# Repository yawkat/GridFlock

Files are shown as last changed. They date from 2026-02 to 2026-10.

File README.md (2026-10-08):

# GridFlock

A gridfinity-compatible baseplate generator for small printer beds. Cuts the base plate into pieces that fit the printer bed and can be linked together using puzzle-style locking connectors. 

<div align="center">
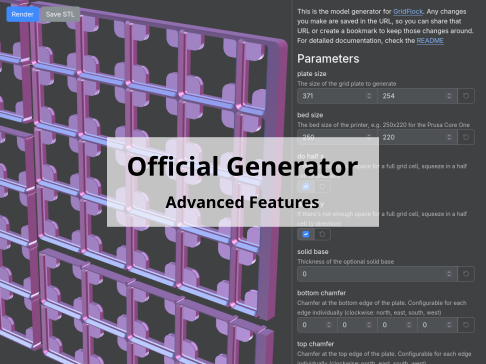
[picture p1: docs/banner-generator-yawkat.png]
Official Generator: Advanced Features
  
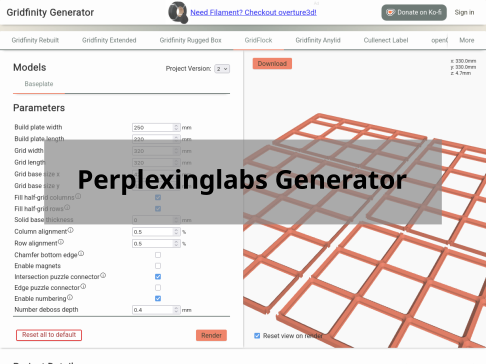
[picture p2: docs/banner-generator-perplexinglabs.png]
Perplexinglabs Generator
  
</div>

An online generator for the latest version version of GridFlock is available [here](https://gridflock.yawk.at/?utm_source=github&utm_campaign=readme_gridflock). You can also use [the perplexinglabs generator](https://gridfinity.perplexinglabs.com/pr/gridflock/0/0) which is a bit more stable. Please also support the model page [on Printables](https://www.printables.com/model/1579487-gridflock-gridfinity-baseplate-generator).

Similar projects include GridPlates (DMCA'd) and GRIPS, but GridFlock is an independent, open-source, clean-room implementation. My goal is truly open community development. If you are missing a feature that is available in GridPlates or GRIPS, please create a GitHub ticket.

GridFlock uses [Gridfinity Rebuilt](https://github.com/kennetek/gridfinity-rebuilt-openscad) (under MIT license) for the baseplate cutter.

For inserting magnets, check out [the jig](#jig).

<!-- openscad -o docs/images/whole.png --camera=0,-10,0,40,0,10,900 -D plate_size='[420, 420]' -->
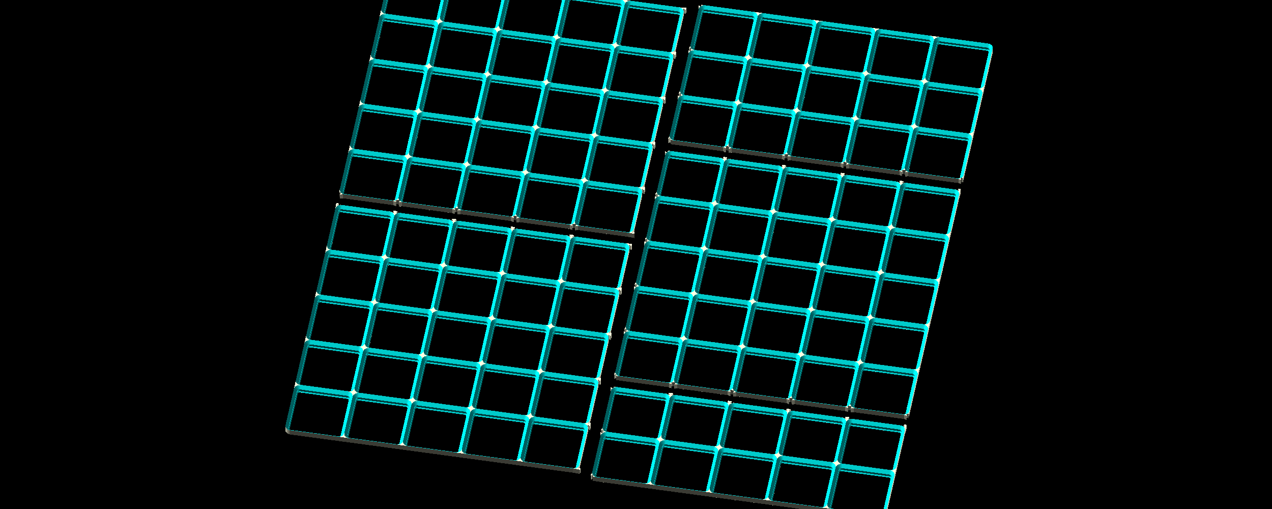
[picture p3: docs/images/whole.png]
Whole plate


<!-- openscad -o docs/images/closeup.png --camera=0,30,0,40,0,25,300 -D plate_size='[420, 420]' -->
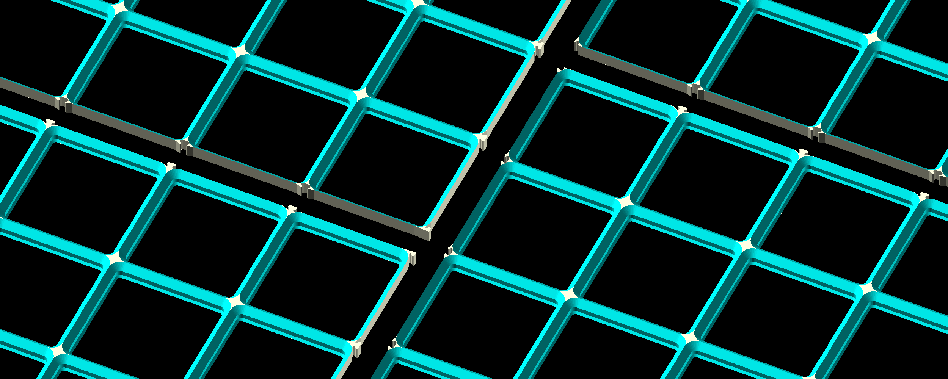
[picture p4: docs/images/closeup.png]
Closeup


- [GridFlock](#gridflock)
  - [Connectors](#connectors)
    - [Intersection Puzzle](#intersection-puzzle)
      - [Connector Fit](#connector-fit)
    - [Edge Puzzle](#edge-puzzle)
      - [Connector Height](#connector-height)
      - [Connector Count](#connector-count)
  - [Magnets](#magnets)
    - [No Magnets](#no-magnets)
    - [Press-Fit magnets](#press-fit-magnets)
      - [Jig](#jig)
    - [Release slot](#release-slot)
    - [Glued magnets](#glued-magnets)
    - [Rounded corner frame](#rounded-corner-frame)
      - [Magnet border](#magnet-border)
    - [Solid frame](#solid-frame)
  - [Click Latch](#click-latch)
    - [ClickGroove](#clickgroove)
      - [Special Bins](#special-bins)
      - [Gap Length](#gap-length)
      - [Tab Length](#tab-length)
      - [Depth](#depth)
      - [Latch Strength](#latch-strength)
      - [Latch Wall Strength](#latch-wall-strength)
    - [Arc Style Latch](#arc-style-latch)
      - [Length](#length)
      - [Distance](#distance)
      - [Latch Strength](#latch-strength-1)
      - [Latch Wall Strength](#latch-wall-strength-1)
      - [Height](#height)
      - [Steepness](#steepness)
  - [Filler](#filler)
    - [None](#none)
    - [Integer Fraction](#integer-fraction)
    - [Dynamic](#dynamic)
  - [Lightweight](#lightweight)
    - [Wall thickness](#wall-thickness)
    - [Connector fill](#connector-fill)
    - [Bottom lip](#bottom-lip)
  - [Corner radius](#corner-radius)
  - [Alignment](#alignment)
  - [Custom cell size](#custom-cell-size)
  - [Solid base](#solid-base)
  - [Bottom Chamfer](#bottom-chamfer)
  - [Top Chamfer](#top-chamfer)
  - [Numbering](#numbering)
    - [Squeezed number](#squeezed-number)
  - [Plate Wall](#plate-wall)
    - [Top plate wall](#top-plate-wall)
    - [Bottom plate wall](#bottom-plate-wall)
    - [Variable wall height](#variable-wall-height)
  - [openGrid Adapter](#opengrid-adapter)
    - [Adapter types](#adapter-types)
      - [Standard openGrid](#standard-opengrid)
      - [openConnect](#openconnect)
  - [Intersection Holes](#intersection-holes)
    - [Screw dimensions](#screw-dimensions)
    - [Intersection magnets](#intersection-magnets)
      - [Magnet dimensions](#magnet-dimensions)
      - [Magnet floor](#magnet-floor)
      - [Magnet release hole](#magnet-release-hole)
    - [Hole locations](#hole-locations)
      - [Plate corners](#plate-corners)
      - [Plate edges](#plate-edges)
      - [Segment corners](#segment-corners)
      - [Segment edges](#segment-edges)
      - [Other intersections](#other-intersections)
      - [Combined](#combined)
  - [Horizontal Screws](#horizontal-screws)
  - [Thumb Screw](#thumb-screw)
  - [Segmentation](#segmentation)
    - [Horizontal](#horizontal)
    - [Vertical](#vertical)
    - [Separate edge padding](#separate-edge-padding)
  - [Edge Adjustment](#edge-adjustment)
    - [Shifting the grid](#shifting-the-grid)
    - [Adding empty space](#adding-empty-space)
    - [Squeezing in extra cells](#squeezing-in-extra-cells)
  - [Top Slice](#top-slice)
  - [Stacked Print](#stacked-print)
    - [Segment Gap](#segment-gap)
    - [Duplicates](#duplicates)
    - [Flipping](#flipping)
    - [Top Slice](#top-slice-1)
  - [Cell override](#cell-override)
    - [Normal cell](#normal-cell)
    - [Solid](#solid)
    - [Empty](#empty)
    - [Irregular Shapes](#irregular-shapes)
  - [Building from source](#building-from-source)
  - [Why the name?](#why-the-name)

## Connectors

When the plate size exceeds your printer's bed size, GridFlock will split the plate into multiple pieces called 'segments'. To connect these segments, multiple connector designs are available.

### Intersection Puzzle

[Interactive example](https://gridflock.yawk.at/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)

This mode adds small puzzle-style connectors at cell intersections. This is similar to GridPlates and GRIPS, and relatively easy to print. However, in my experience, these connectors can sometimes lead to gaps between the segments. The shape of these connectors is fixed in [puzzle.svg](https://github.com/yawkat/GridFlock/blob/main/puzzle.svg) and cannot be customized without editing the SVG.

<!-- openscad -o docs/images/intersection-puzzle.png --camera=0,30,0,40,0,25,300 -D plate_size='[420, 420]' -->
Intersection puzzle

#### Connector Fit

The intersection puzzle connector is intentionally tight to produce a secure fit. It may be necessary to use a mallet or hammer to connect plates.

If the puzzle connector is too tight for your print settings, you can use the `intersection_puzzle_fit` parameter to produce a looser fit. A value of 0 produces the loosest fit, while 1 is the tightest. Try multiple settings and see which works best for you. Tight fit example (`intersection_puzzle_fit=1`):

<!-- openscad -o docs/images/intersection-puzzle-tight.png --camera=0,0,0,40,0,25,70 -D plate_size='[84, 84]' -D bed_size='[50, 1000]' -D magnets=false -->
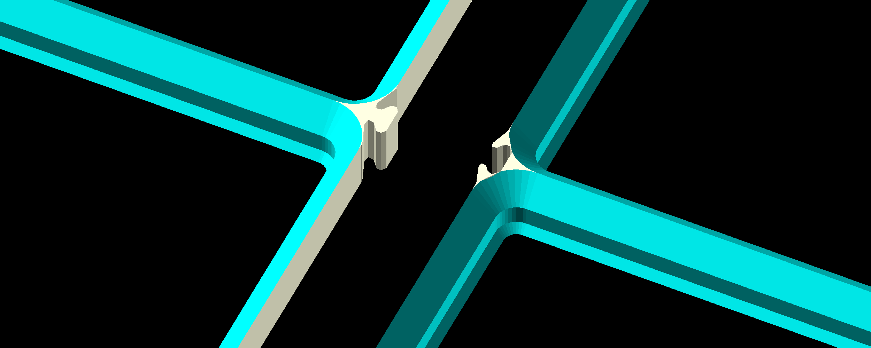
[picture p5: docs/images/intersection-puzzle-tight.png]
Intersection puzzle (tight)


Loose fit example (`intersection_puzzle_fit=0`):

<!-- openscad -o docs/images/intersection-puzzle-loose.png --camera=0,0,0,40,0,25,70 -D plate_size='[84, 84]' -D bed_size='[50, 1000]' -D magnets=false -D intersection_puzzle_fit=0 -->
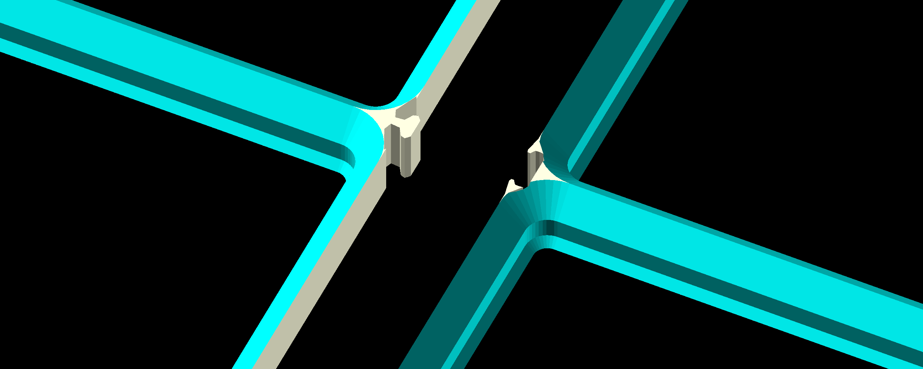
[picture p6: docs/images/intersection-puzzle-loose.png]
Intersection puzzle (loose)


You can find small grids with different fit values to calibrate [on printables](https://www.printables.com/model/1579487-gridflock-gridfinity-baseplate-generator/files).

### Edge Puzzle

[Interactive example](https://gridflock.yawk.at/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)

The edge puzzle mode uses larger connectors placed at the edges of cells, instead of intersections. This leads to a more accurate fit, but is a bit harder to print, and uses more filament.

This connector is a good alternative to the intersection puzzle if the plate has enough vertical height. Try both and see what works best for you. You can also technically enable both at the same time, though I don't know why you would.

* At a segment corner where female connectors are placed on both adjacent sides, the corner could be "cut off" from the rest of the segment. To avoid this, the connector does not use the full height. When *not* using magnets, this can make the connector quite flimsy.
* To avoid interference with the bin in the neighbouring cell, the male connector has a cutout identical to the bin in that cell. Again, if there is not enough vertical height (no magnets), this can make the male connector flimsy.
* To make the female connectors more sturdy and easier to print, an extra "bar" is added at the magnet level, on those edges where a female connector is placed (only if magnets are enabled). You can see it in the screenshot. With this bar, it may be viable to make the connector full-height and avoid the overhang.
* Unlike the intersection mode, the edge puzzle connectors are highly customizable for your circumstances.

<!-- openscad -o docs/images/edge-puzzle.png --camera=0,30,0,40,0,25,300 -D plate_size='[420, 420]' -D connector_intersection_puzzle=false -D connector_edge_puzzle=true -D magnets=true -->
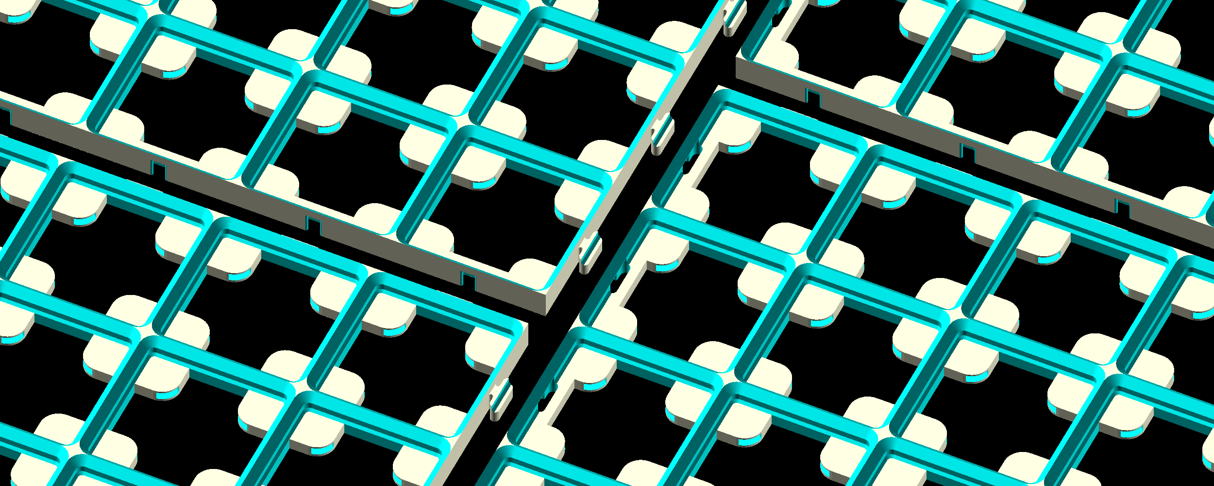
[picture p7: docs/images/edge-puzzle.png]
Edge puzzle


<!-- regression tests: -->
<!-- openscad -o docs/images/edge-puzzle-clickgroove.png --camera=0,0,0,10,0,10,400 -D plate_size='[168, 168]' -D bed_size='[100,100]' -D connector_intersection_puzzle=false -D connector_edge_puzzle=true -D click=true -D click_style=1 -->

#### Connector Height

The edge puzzle connector height can be configured using the `edge_puzzle_height_female` property. The male connector is smaller than this option by `edge_puzzle_height_male_delta`.

With default settings, the male side of the connector can only be pushed into the female side from below. If you increase the `edge_puzzle_height_female` to e.g. 10mm, it will use the full height, and the connector can be pushed from both sides.

<!-- openscad -o docs/images/edge-puzzle-full-height.png --camera=0,0,0,40,0,10,200 -D plate_size='[84, 63]' -D connector_intersection_puzzle=false -D connector_edge_puzzle=true -D 'bed_size=[50, 80]' -D magnets=true -D edge_puzzle_height_female=10 -->
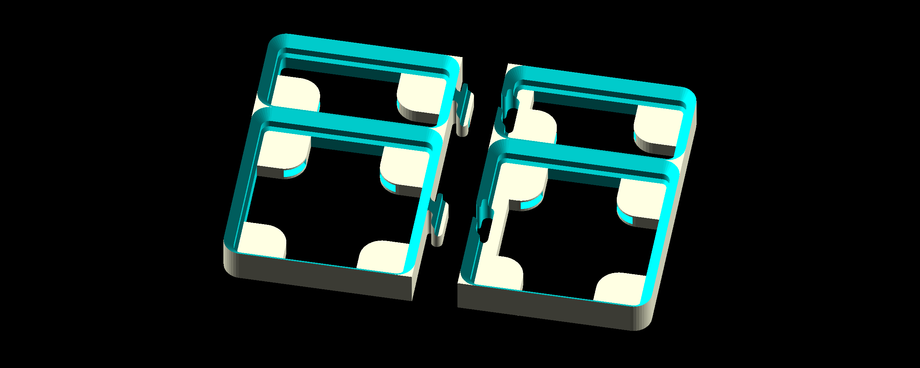
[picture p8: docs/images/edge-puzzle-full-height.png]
Edge puzzle connector with full height


The problem with the full-height connector is that it can lead to unconnected pieces if there is no magnet layer for support. You can see in the below example that the bottom left corner of the top right segment has no connection to the rest of the segment.

<!-- openscad -o docs/images/edge-puzzle-unconnected.png --camera=0,0,0,40,0,10,200 -D plate_size='[84, 84]' -D connector_intersection_puzzle=false -D connector_edge_puzzle=true -D 'bed_size=[50, 50]' -D magnets=false -D edge_puzzle_height_female=10 -->
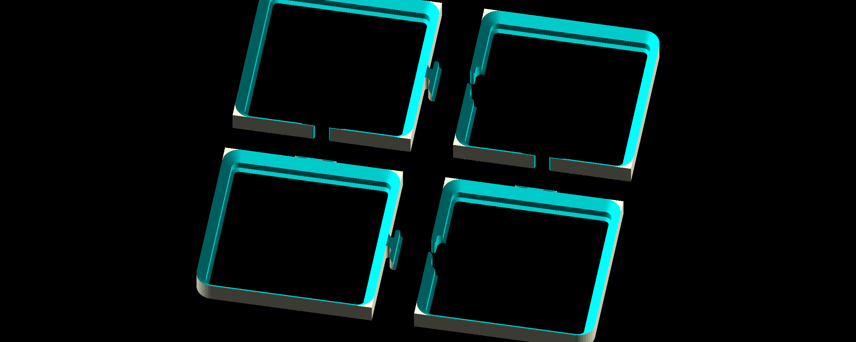
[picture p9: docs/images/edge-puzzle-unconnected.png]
Edge puzzle connector with full height leading to unconnected part


#### Connector Count

The connector count can be configured using the `edge_puzzle_count` property.

<!-- openscad -o docs/images/edge-puzzle-multi.png --camera=0,0,0,40,0,10,200 -D plate_size='[84, 63]' -D connector_intersection_puzzle=false -D connector_edge_puzzle=true -D 'bed_size=[50, 80]' -D magnets=true -D edge_puzzle_count=3 -->
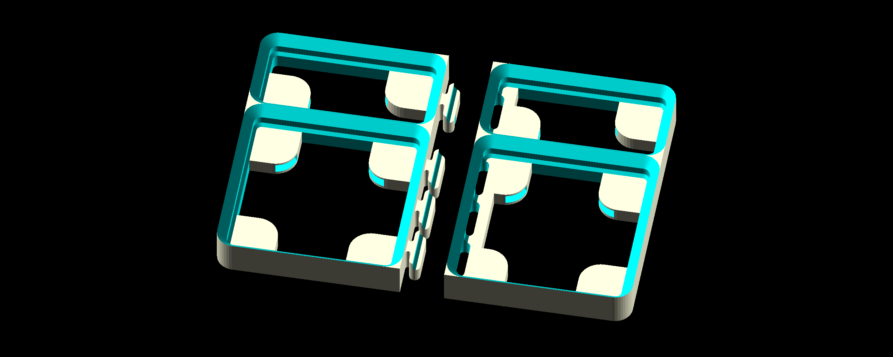
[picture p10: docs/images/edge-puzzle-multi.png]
Multiple edge puzzle connectors


## Magnets

GridFlock supports the standard Gridfinity magnet layout. Note that magnets require additional vertical room.

Magnets are assumed to be round. The exact size can be configured with the `magnet_diameter` and `magnet_height` options.

### No Magnets

It is possible to disable magnets altogether to save filament and vertical space.

<!-- openscad -o docs/images/magnets-none.png --camera=0,0,0,40,0,10,200 -D plate_size='[105, 63]' -D magnets=false -->
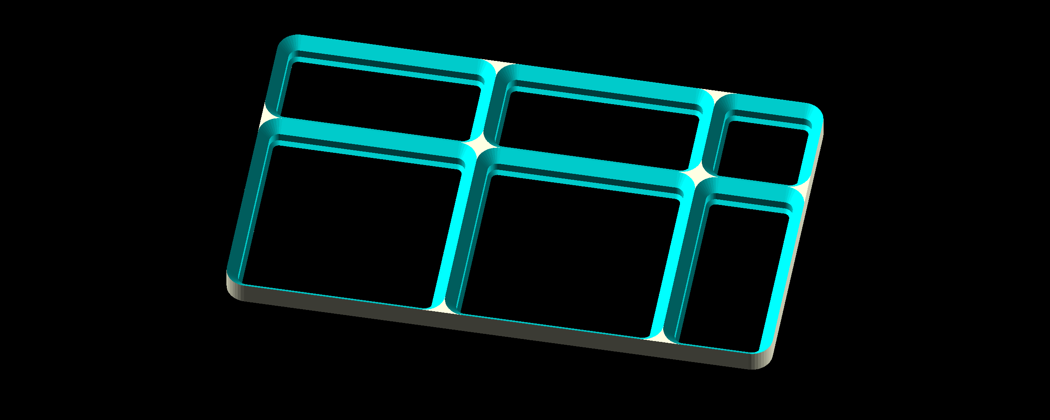
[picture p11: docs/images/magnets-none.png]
No Magnets


### Press-Fit magnets

Press-fit magnets require no glue. The magnets are simply pressed into the pockets from the side. A jig for easily inserting magnets is available [on printables](https://www.printables.com/model/1579487-gridflock-gridfinity-baseplate-generator/files) (thanks @nelsonjchen!).

<!-- openscad -o docs/images/magnets-press-fit.png --camera=0,0,0,40,0,10,200 -D plate_size='[105, 63]' -D magnets=true -->
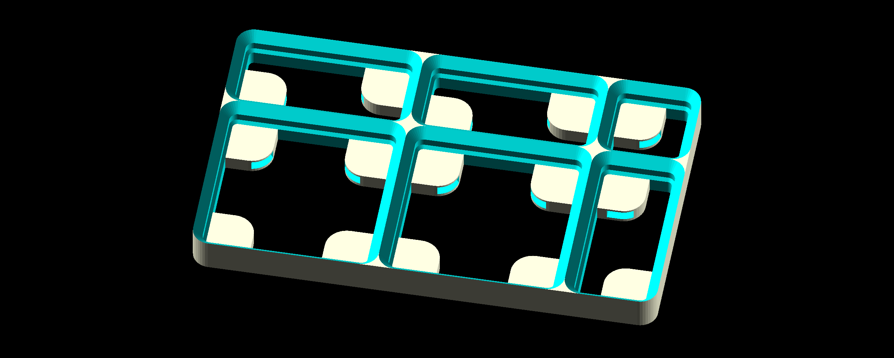
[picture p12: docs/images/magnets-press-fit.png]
Press-fit magnets


The layers above and below the magnet can be configured using the `magnet_top` and `magnet_bottom` options. 

Because the distance to the bin magnets is larger, press-fit magnets make for a weaker connection than glue-in magnets.

#### Jig

GridFlock includes a magnet insertion jig that makes pressing in magnets easy and fast (thanks @nelsonjchen!). You can download the jig [on printables](https://www.printables.com/model/1579487-gridflock-gridfinity-baseplate-generator/files). There is also [a remix available](https://www.printables.com/model/1640587-gridflock-magnet-jig-tweaked) that improves the jig further. Note that the remix is not generated as part of GridFlock, so future geometry changes may not be included (see [issue](https://github.com/yawkat/GridFlock/issues/39)).

The jig prints in two pieces, a main frame and a pusher. The pusher needs to be printed with supports, and should have a high infill percentage.

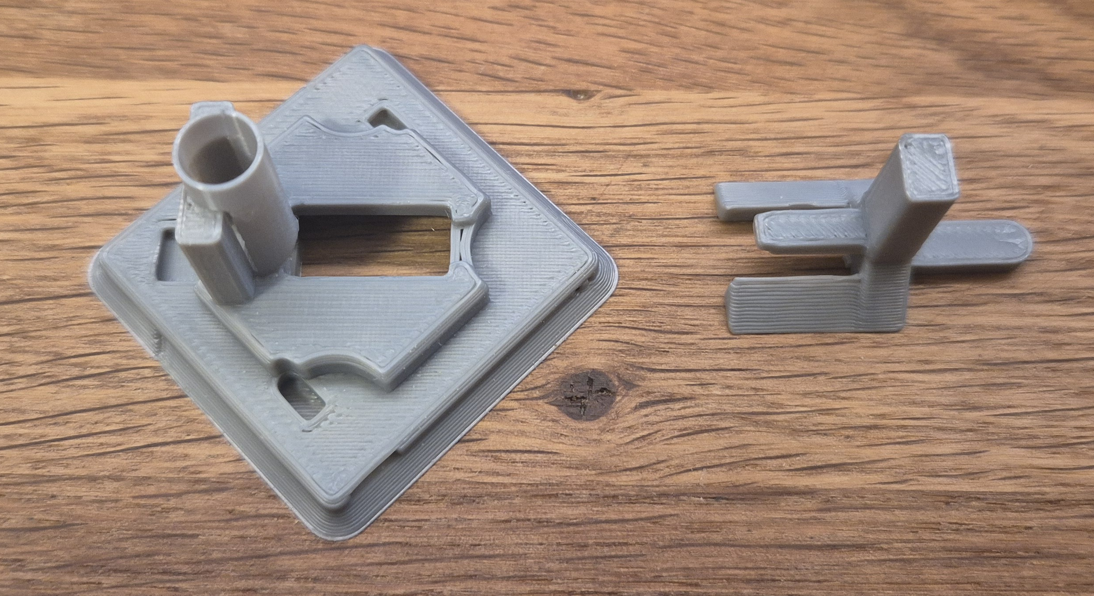
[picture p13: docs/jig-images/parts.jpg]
Jig parts


First, insert the reference magnet. The reference magnet will make sure that any magnets you put into the plate will have the right orientation, and it helps with pulling the magnets into place. Make sure it has the right orientation – see the below instructions on how the jig is used to figure it out. Place the reference magnet in the circled slot:

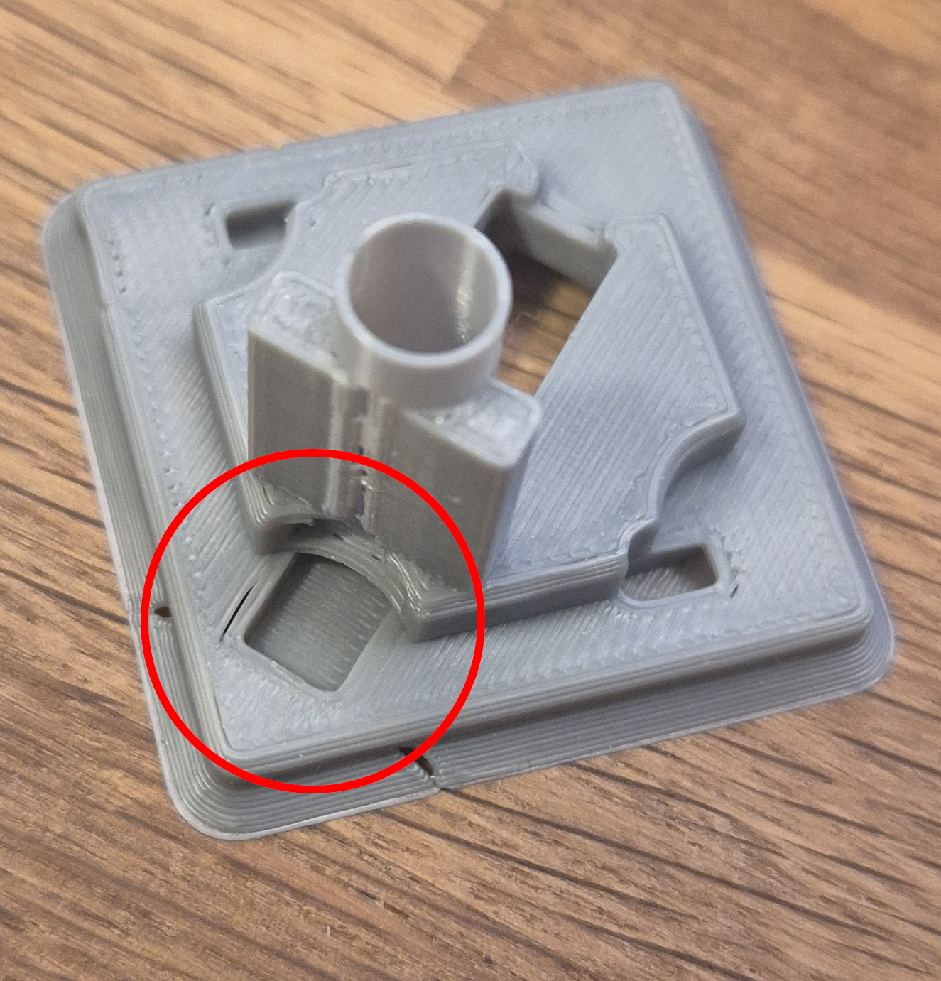
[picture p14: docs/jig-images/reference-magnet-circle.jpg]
The jig with a circle around the reference magnet slot


Next, push the reference magnet into the jig until it is fully seated. Here you can see it halfway:

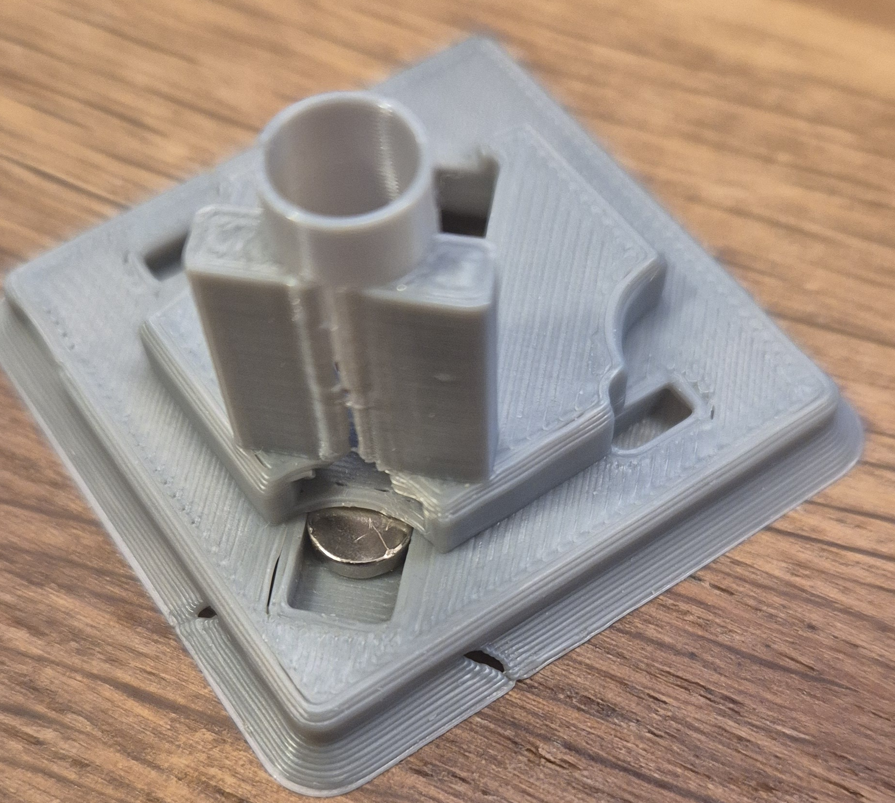
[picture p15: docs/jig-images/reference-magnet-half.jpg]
Reference magnet inserted half-way


Now, place the jig on top of the pusher to finish assembly:

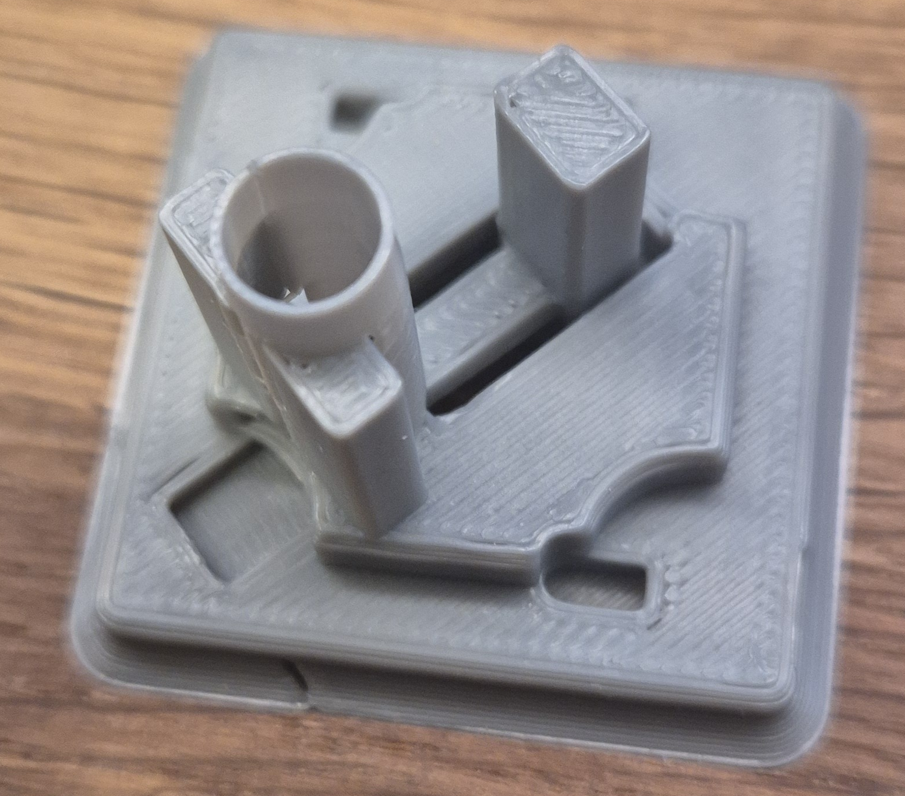
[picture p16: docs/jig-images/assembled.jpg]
Assembled jig


Now that the jig is assembled, you can start using it to populate your baseplate. Load a stack of magnets into the jig, and then place the baseplate upside down on the jig:

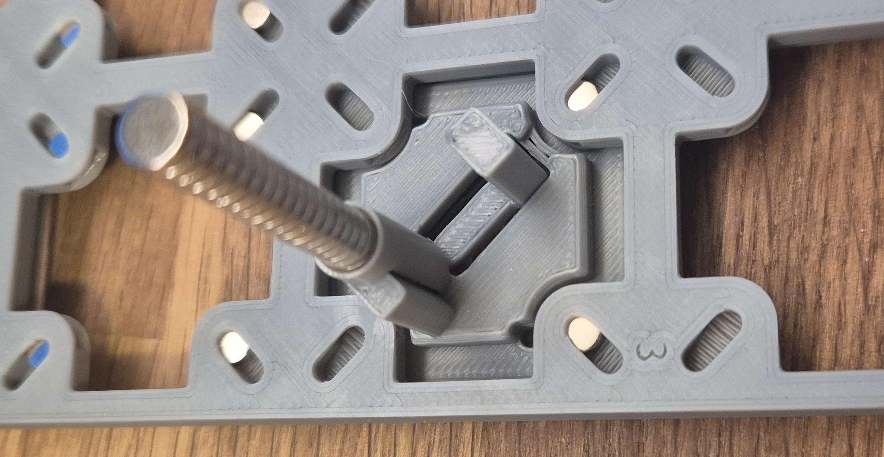
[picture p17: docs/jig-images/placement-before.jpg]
Baseplate on top of the jig


Now you can use the pusher to insert the magnet into the baseplate:

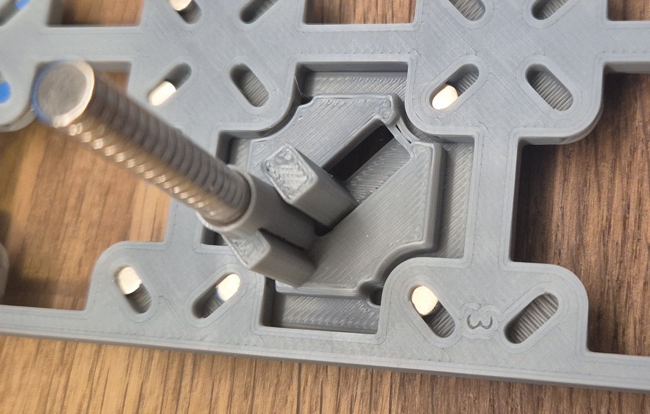
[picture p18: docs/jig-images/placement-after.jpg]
Baseplate on top of the jig with magnet pushed in


Pull the pusher back into its original position to release the baseplate. You can now turn the jig by 90° to insert the next magnet, and then move the baseplate to fill the next square with magnets.

<!-- These images are generated for regression detection purposes. -->
<!-- openscad -o docs/images/jig-main.png --camera=0,0,0,40,0,10,200 -D part='"jig"' mag_insert_jig.scad -->
<!-- openscad -o docs/images/jig-pusher.png --camera=0,0,0,40,0,10,200 -D part='"pusher"' mag_insert_jig.scad -->
<!-- openscad -o docs/images/jig-main-below.png --camera=0,0,0,140,0,10,200 -D part='"jig"' mag_insert_jig.scad -->
<!-- openscad -o docs/images/jig-pusher-below.png --camera=0,0,0,140,0,10,200 -D part='"pusher"' mag_insert_jig.scad -->

### Release slot

On the bottom side of the plate there is a slot so you can push out any inserted magnet with a screwdriver.

<!-- openscad -o docs/images/magnets-press-fit-below.png --camera=0,0,0,140,0,10,200 -D plate_size='[105, 63]' -D magnets=true -->
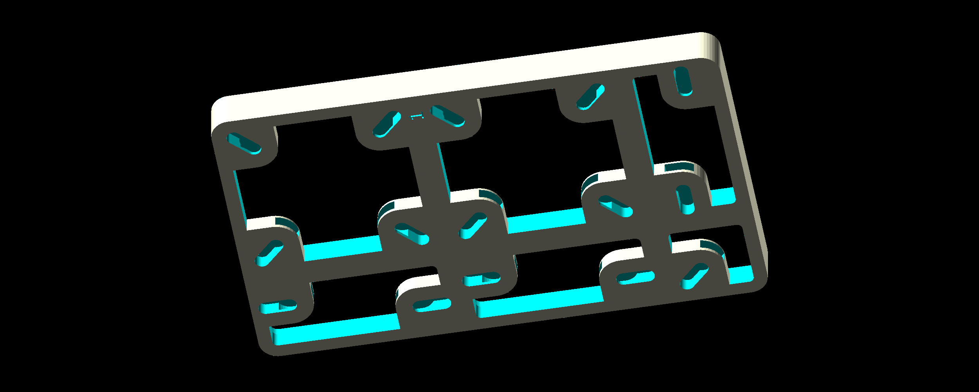
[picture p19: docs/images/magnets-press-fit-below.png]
Press-fit magnets from below


The width of this slot can be adjusted with the `magnet_release_width` setting. Setting this to 0 disables the release slot.

For glue-in magnets, there is a hole instead of a slot. The diameter of the hole is also controlled by `magnet_release_width`.

### Glued magnets

Magnets can also be glued in from the top:

<!-- openscad -o docs/images/magnets-glue-in.png --camera=0,0,0,40,0,10,200 -D plate_size='[105, 63]' -D magnets=true -D magnet_style=0 -->
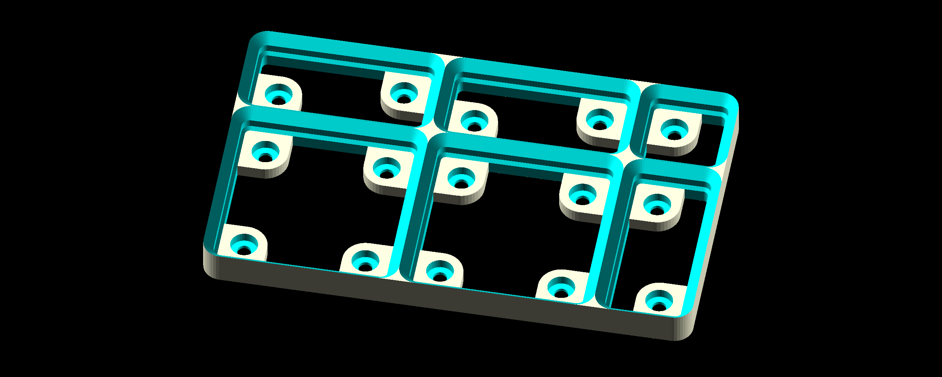
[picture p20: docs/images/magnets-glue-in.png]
Glued magnets (top)


The `magnet_bottom` option is identical to the press-fit version, but the `magnet_top` option is ignored.

Or they can be glued from the bottom:

<!-- openscad -o docs/images/magnets-glue-in-bottom.png --camera=0,0,0,140,0,10,200 -D plate_size='[105, 63]' -D magnets=true -D magnet_style=2 -->
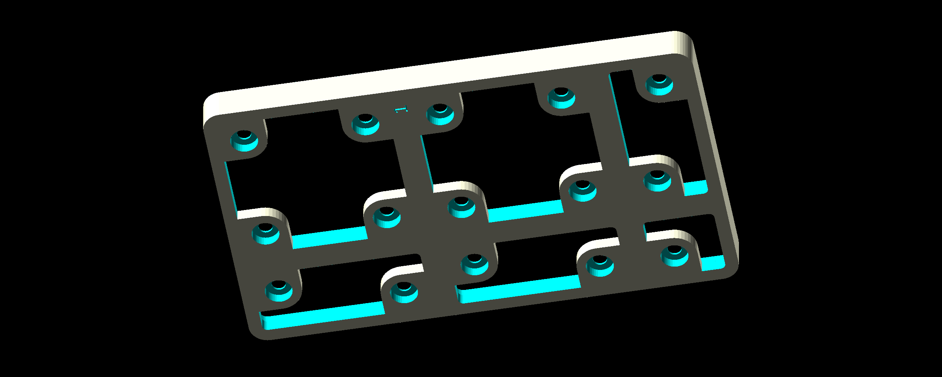
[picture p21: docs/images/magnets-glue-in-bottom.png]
Glued magnets (bottom)


By tuning the magnet size, this last magnet style can also be used to press-fit magnets from the bottom, similar to Gridfinity Refined.

### Rounded corner frame

By default, the vertical space for the magnet is not fully filled in to save filament. This is called the "rounded corner" frame style.

Press-fit magnets

#### Magnet border

To save filament, you can set a lower `magnet_border`:

<!-- openscad -o docs/images/magnet-border-1.png --camera=0,0,0,40,0,10,200 -D plate_size='[105, 63]' -D magnets=true -D magnet_border=1 -D magnet_style=1 -->
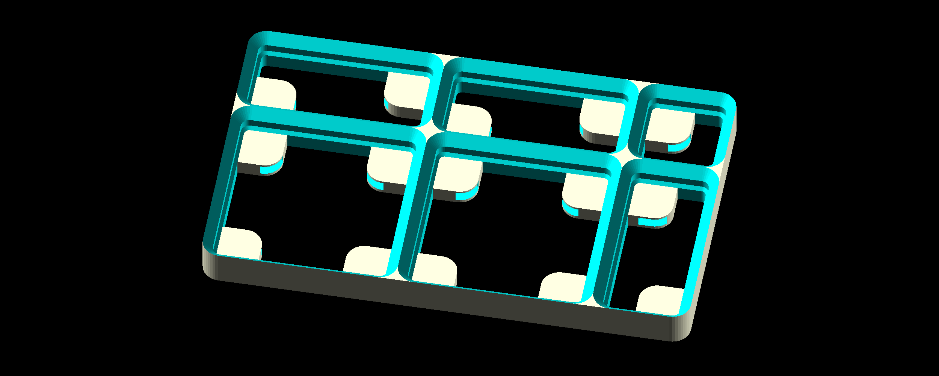
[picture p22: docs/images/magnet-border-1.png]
Magnet border


### Solid frame

Using the `magnet_frame_style` option, you can change the magnet layer to be fully filled in.

> [!WARNING]
> The solid frame style cannot be combined with the press-fit magnet style because there is no way to push the magnets in.

<!-- openscad -o docs/images/magnets-solid.png --camera=0,0,0,40,0,10,200 -D plate_size='[105, 63]' -D magnets=true -D magnet_style=0 -D magnet_frame_style=0 -->
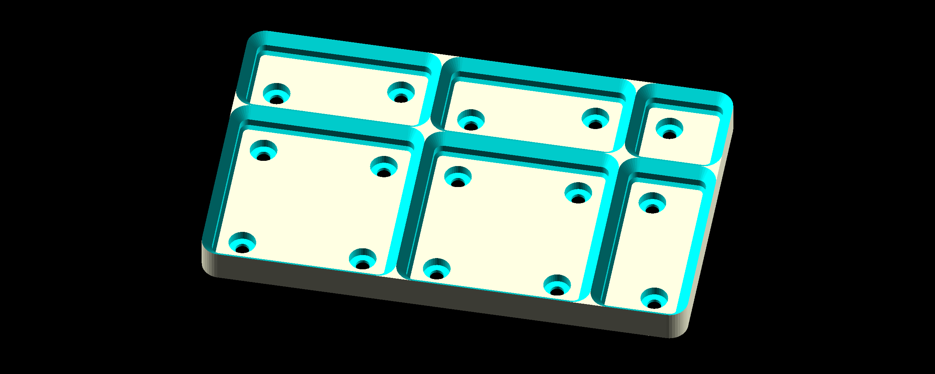
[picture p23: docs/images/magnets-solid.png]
Solid magnet frame


## Click Latch

If you do not wish to use magnets, but still want a more secure fit for your bins, a click latch is an option. A click latch grips the bottom of the bin.

> [!WARNING]
> When a bin is placed on the baseplate, the click latch is under constant mechanical stress. This causes the plastic to deform over time ("creep"), reducing the grip strength. _PLA is very susceptible to this._ PETG is more resistant, but long-term tests are still scarce, so _consider this feature experimental_.

### ClickGroove

Like other click latch designs, a ClickGroove baseplate works with standard Gridfinity bins, with similar creep problems. When used with a ClickGroove bin, however, a special notch in the bin's base allows the baseplate to grab on _without stress_, which reduces long term creep.

<!-- openscad -o docs/images/click2.png --camera=0,0,0,40,0,10,200 -D plate_size='[105, 63]' -D click=true -D click_style=1 -->
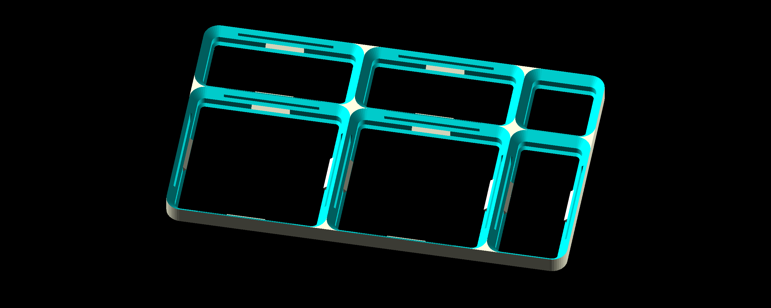
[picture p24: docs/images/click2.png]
ClickGroove baseplate


<!-- regression testing: -->
<!-- openscad -o docs/images/click2-bottom-chamfer-1.png --camera=0,0,0,140,0,10,200 -D plate_size='[86, 86]' -D click=true -D click_style=1 -D bottom_chamfer='[0,0,0,0]' -->
<!-- openscad -o docs/images/click2-bottom-chamfer-2.png --camera=0,0,0,140,0,10,200 -D plate_size='[86, 86]' -D click=true -D click_style=1 -D bottom_chamfer='[1,1,0,0]' -->
<!-- openscad -o docs/images/click2-bottom-chamfer-3.png --camera=0,0,0,140,0,10,200 -D plate_size='[86, 86]' -D click=true -D click_style=1 -D bottom_chamfer='[2,2,1,1]' -->
<!-- openscad -o docs/images/click2-bottom-chamfer-4.png --camera=0,0,0,140,0,10,200 -D plate_size='[86, 86]' -D click=true -D click_style=1 -D bottom_chamfer='[3,3,2,2]' -->

#### Special Bins

To avoid creep and take full advantage of the ClickGroove system, your bins need a compatible groove. There is a template bin with this groove [on printables](https://www.printables.com/model/1579487-gridflock-gridfinity-baseplate-generator/files). To add it to a bin, use the [Gridfinity Rebase tool](https://gridfinity.tools/rebase/). The tool can modify community-created bins, or those created with a generator like [Gridfinity Extended](https://docs.ostat.com/docs/openscad/gridfinity-extended).

<!-- openscad -o docs/images/click2-bin.png --camera=0,0,3,80,0,20,50 clickgroove-base.scad -->
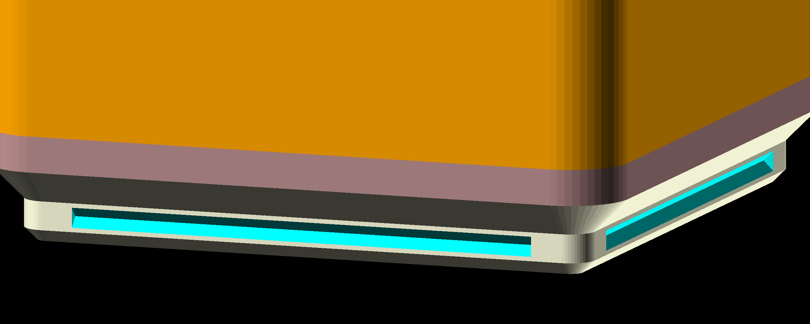
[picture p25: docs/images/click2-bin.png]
ClickGroove bin template


#### Gap Length

The length of the gap behind the click latch can be configured with `clickgroove_gap_length`. A higher value will lead to less resistance when locking and unlocking.

<!-- openscad -o docs/images/click2-gap-length.png --camera=0,0,0,40,0,10,100 -D plate_size='[42, 42]' -D click=true -D click_style=1 -D clickgroove_gap_length=10 -->
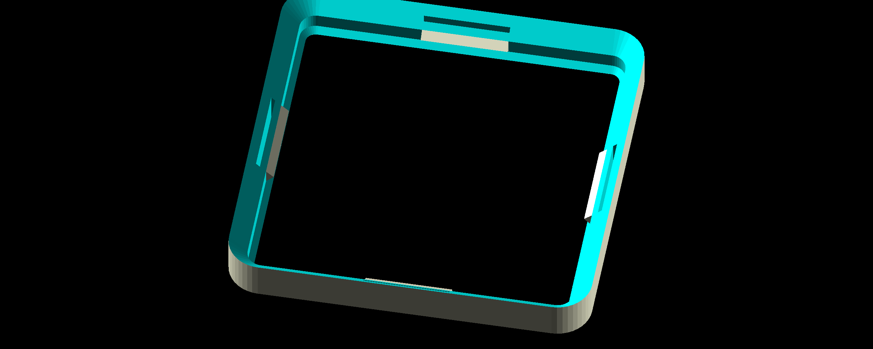
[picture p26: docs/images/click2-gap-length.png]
Click latch with clickgroove_gap_length=10


#### Tab Length

The length of the tab that engages with the bin groove can be configured with `clickgroove_tab_length`.

<!-- openscad -o docs/images/click2-tab-length.png --camera=0,0,0,40,0,10,100 -D plate_size='[42, 42]' -D click=true -D click_style=1 -D clickgroove_tab_length=5 -->
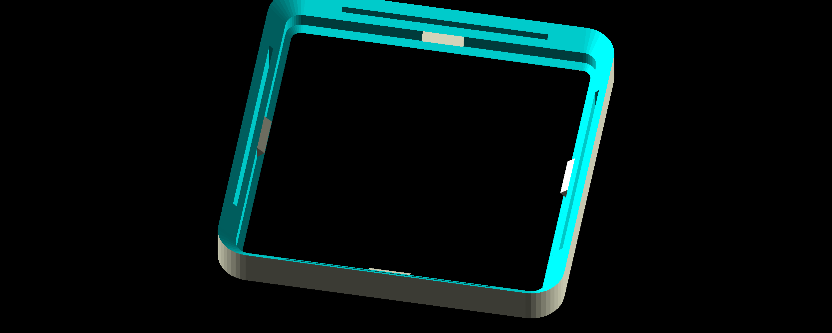
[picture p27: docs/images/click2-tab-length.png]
Click latch with clickgroove_tab_length=5


#### Depth

The depth of the tab can be configured with `clickgroove_depth`. Changing this value has a big impact on latching strength, so be careful.

<!-- openscad -o docs/images/click2-depth.png --camera=0,0,0,40,0,10,100 -D plate_size='[42, 42]' -D click=true -D click_style=1 -D clickgroove_depth=2 -->
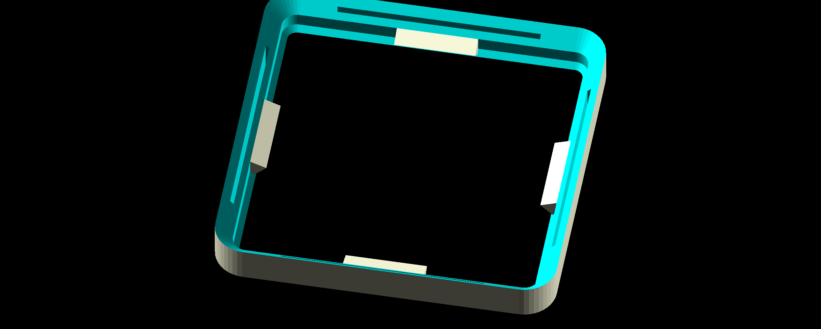
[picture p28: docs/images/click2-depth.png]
Click latch with clickgroove_depth=2


#### Latch Strength

The `clickgroove_strength` property controls the thickness of the latch itself. This is measured from the very bottom of the latch which, if you look at the gridfinity specification, has a chamfer of 0.7mm, so the strength needs to be higher than this to get any reasonable latch height. Here's an example with `clickgroove_strength=2.5` (and `clickgroove_wall_strength=0`, or else there would not be enough space):

<!-- openscad -o docs/images/click1-strength-2.5.png --camera=0,0,0,40,0,10,100 -D plate_size='[42, 42]' -D click=true -D click_style=1 -D clickgroove_strength=2.5 -D clickgroove_wall_strength=0 -->
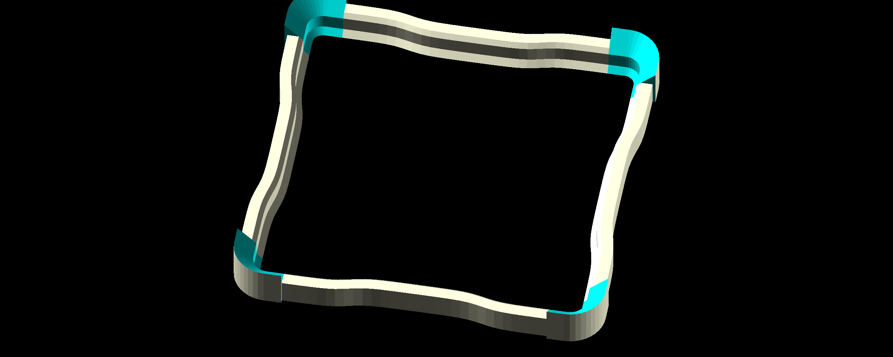
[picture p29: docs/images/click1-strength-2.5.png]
Click latch with clickgroove_strength=2.5


#### Latch Wall Strength

The `clickgroove_wall_strength` property controls the thickness of the wall behind the latch. This wall serves two purposes: It adds rigidity to the baseplate, and it prevents the click latch from bending too far. Note that the wall is measured per cell, so if you have two neighbouring cells, the actual wall thickness will be double this value. An example with `clickgroove_wall_strength=2` (and reduced `clickgroove_strength`):

<!-- openscad -o docs/images/click1-wall-strength-2.png --camera=0,0,0,40,0,10,100 -D plate_size='[84, 42]' -D click=true -D click_style=1 -D clickgroove_strength=0.8 -D clickgroove_wall_strength=2 -->
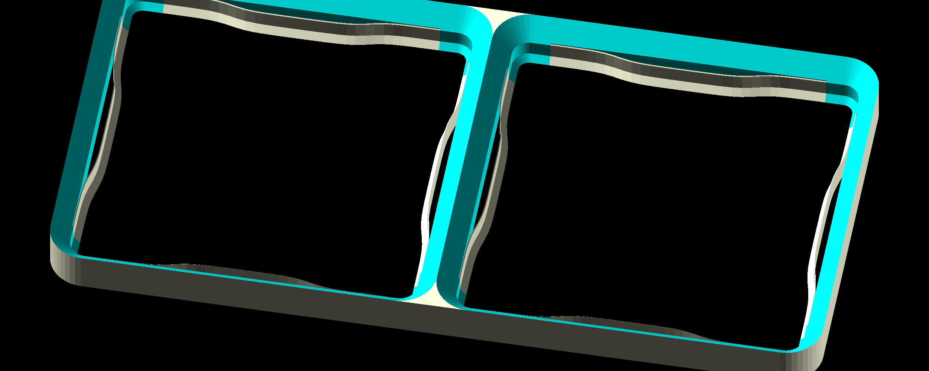
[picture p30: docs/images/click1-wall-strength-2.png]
Click latch with clickgroove_wall_strength=2


### Arc Style Latch

The arc-style latch is a more traditional and robust design. However it is very susceptible to creep.

<!-- openscad -o docs/images/click1.png --camera=0,0,0,40,0,10,200 -D plate_size='[105, 63]' -D click=true -D click_style=0 -->
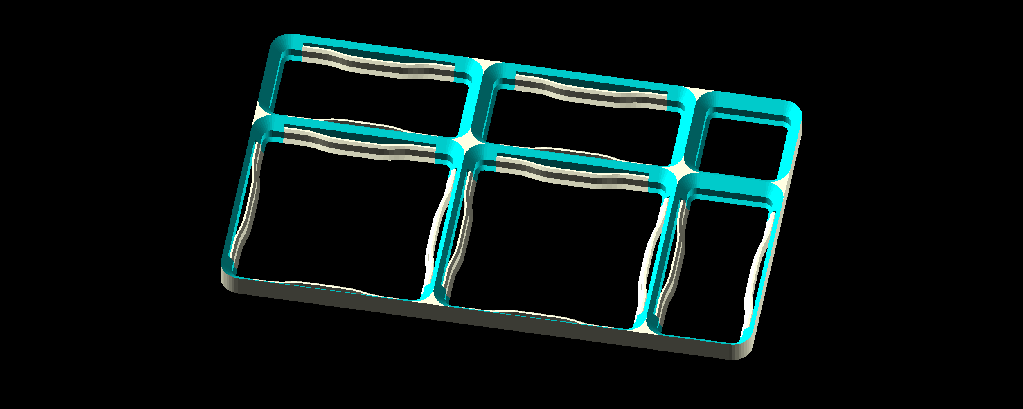
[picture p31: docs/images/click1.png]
Click latch


There are various parameters you can use to tune the click latch mechanism.

#### Length

The latch is composed of two arcs at each end, and an optional middle straight section. The total length of the latch is configured using the `click1_outer_length` property:

<!-- openscad -o docs/images/click1-outer-length-20.png --camera=0,0,0,40,0,10,100 -D plate_size='[42, 42]' -D click=true -D click_style=0 -D click1_outer_length=20 -->
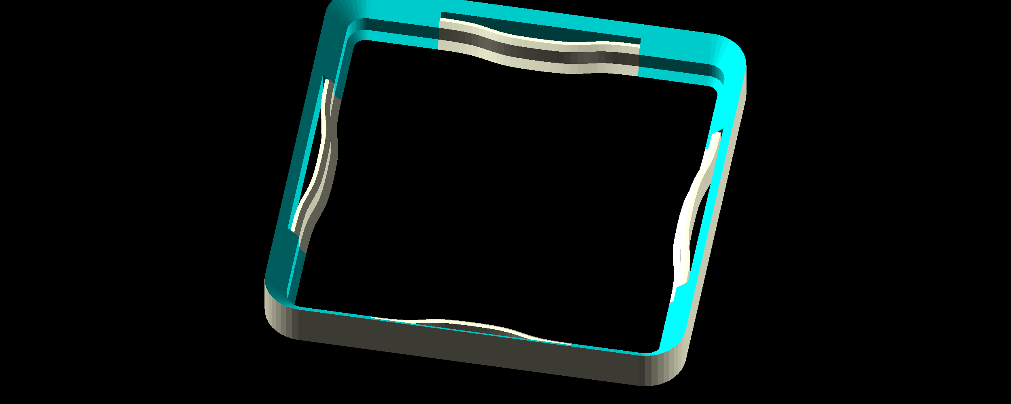
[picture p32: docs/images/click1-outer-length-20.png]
Click latch with click1_outer_length=20


The length of the straight section is configured using `click1_inner_length`, which is 0 by default (no straight section). Here is an example with a 20mm straight section:

<!-- openscad -o docs/images/click1-inner-length-20.png --camera=0,0,0,40,0,10,100 -D plate_size='[42, 42]' -D click=true -D click_style=0 -D click1_inner_length=20 -->
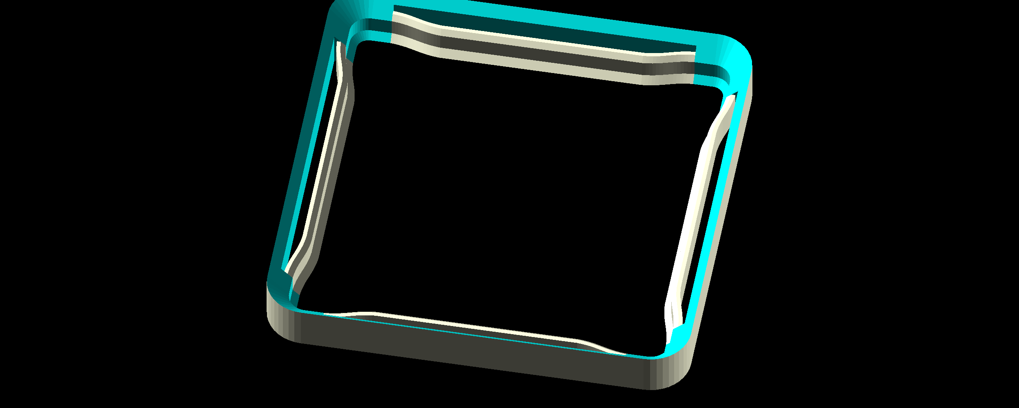
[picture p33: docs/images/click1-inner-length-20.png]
Click latch with click1_inner_length=20


#### Distance

The `click1_distance` property changes the distance that the latch protudes into the bin area. A larger distance can increase grip strength, but makes the bin more difficult to place into the baseplate. Zero distance:

<!-- openscad -o docs/images/click1-distance-0.png --camera=0,0,0,40,0,10,100 -D plate_size='[42, 42]' -D click=true -D click_style=0 -D click1_distance=0 -->
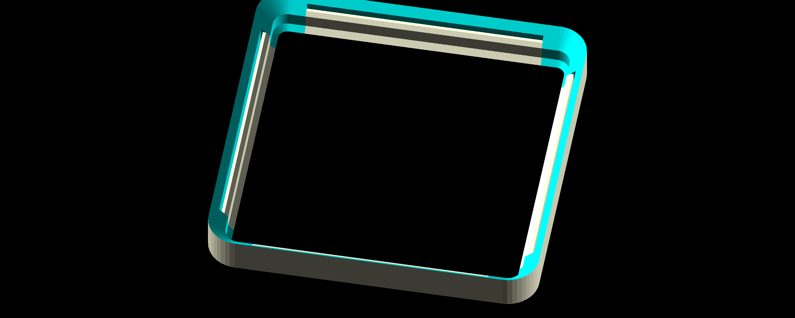
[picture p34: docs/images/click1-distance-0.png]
Click latch with click1_distance=0


5mm distance (don't do this):

<!-- openscad -o docs/images/click1-distance-5.png --camera=0,0,0,40,0,10,100 -D plate_size='[42, 42]' -D click=true -D click_style=0 -D click1_distance=5 -->
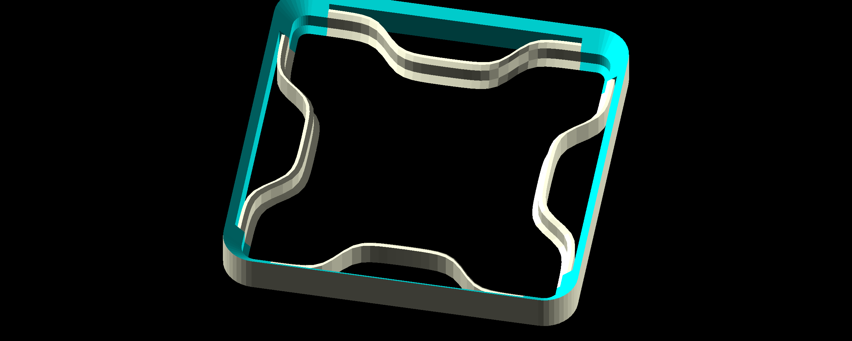
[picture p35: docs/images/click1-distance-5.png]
Click latch with click1_distance=5


#### Latch Strength

The `click1_strength` property controls the thickness of the latch itself. This is measured from the very bottom of the latch which, if you look at the gridfinity specification, has a chamfer of 0.7mm, so the strength needs to be higher than this to get any reasonable latch height. Here's an example with `click1_strength=2.5` (and `click1_wall_strength=0`, or else there would not be enough space):

<!-- openscad -o docs/images/click1-strength-2.5.png --camera=0,0,0,40,0,10,100 -D plate_size='[42, 42]' -D click=true -D click_style=0 -D click1_strength=2.5 -D click1_wall_strength=0 -->
Click latch with click1_strength=2.5

#### Latch Wall Strength

The `click1_wall_strength` property controls the thickness of the wall behind the latch. This wall serves two purposes: It adds rigidity to the baseplate, and it prevents the click latch from bending too far. Note that the wall is measured per cell, so if you have two neighbouring cells, the actual wall thickness will be double this value. An example with `click1_wall_strength=2` (and reduced `click1_strength`):

<!-- openscad -o docs/images/click1-wall-strength-2.png --camera=0,0,0,40,0,10,100 -D plate_size='[84, 42]' -D click=true -D click_style=0 -D click1_strength=0.8 -D click1_wall_strength=2 -->
Click latch with click1_wall_strength=2

Setting the wall strength to 0 disables the backing wall entirely:

<!-- openscad -o docs/images/click1-wall-strength-0.png --camera=0,0,0,40,0,10,100 -D plate_size='[84, 42]' -D click=true -D click_style=0 -D click1_wall_strength=0 -->
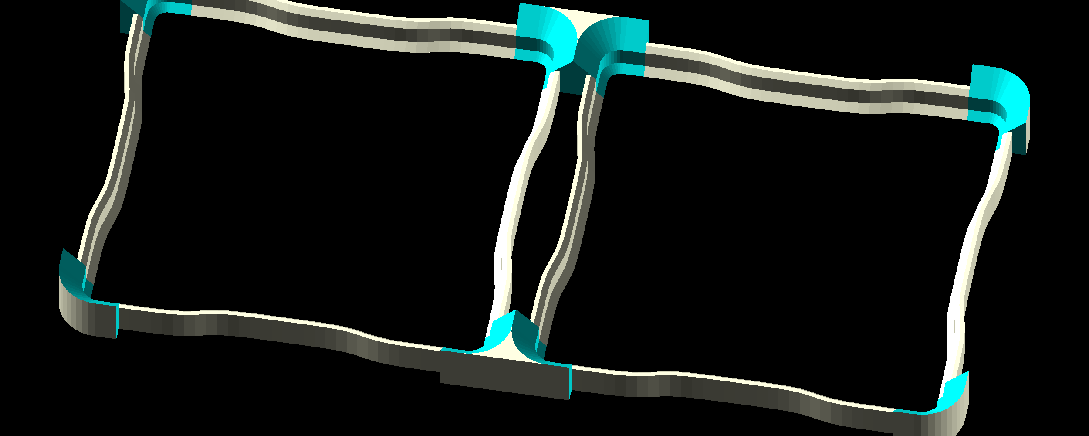
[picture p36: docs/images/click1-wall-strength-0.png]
Click latch with click1_wall_strength=0


#### Height

The `click1_height` property controls the height of the latch.

<!-- openscad -o docs/images/click1-height-0.5.png --camera=0,0,0,40,0,10,100 -D plate_size='[42, 42]' -D click=true -D click_style=0 -D click1_height=0.5 -->
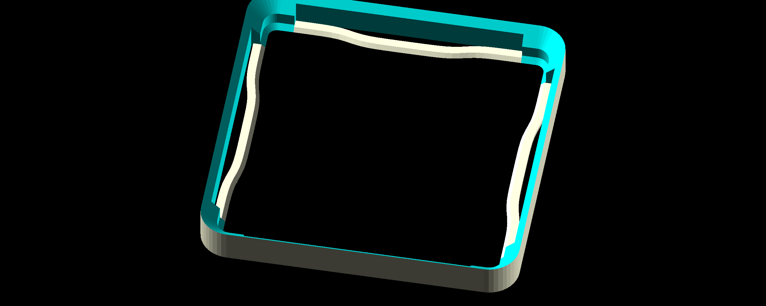
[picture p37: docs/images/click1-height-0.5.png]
Click latch with click1_height=0


#### Steepness

The arcs of the click latch follow a logistic curve, and `click1_steepness` changes the steepness of that curve. Steepness 0.1:

<!-- openscad -o docs/images/click1-steepness-0.1.png --camera=0,0,0,40,0,10,100 -D plate_size='[42, 42]' -D click=true -D click_style=0 -D click1_steepness=0.1 -->
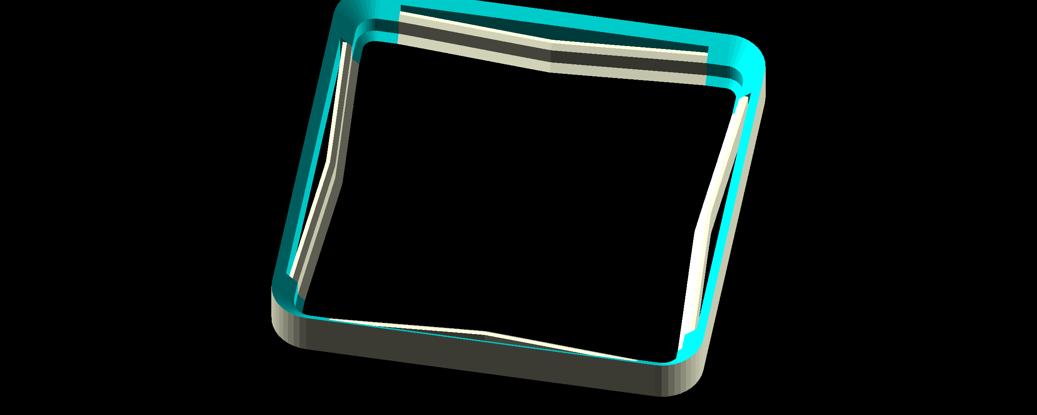
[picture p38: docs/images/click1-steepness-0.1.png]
Click latch with click1_steepness=0.1


Steepness 5:

<!-- openscad -o docs/images/click1-steepness-5.png --camera=0,0,0,40,0,10,100 -D plate_size='[42, 42]' -D click=true -D click_style=0 -D click1_steepness=5 -->
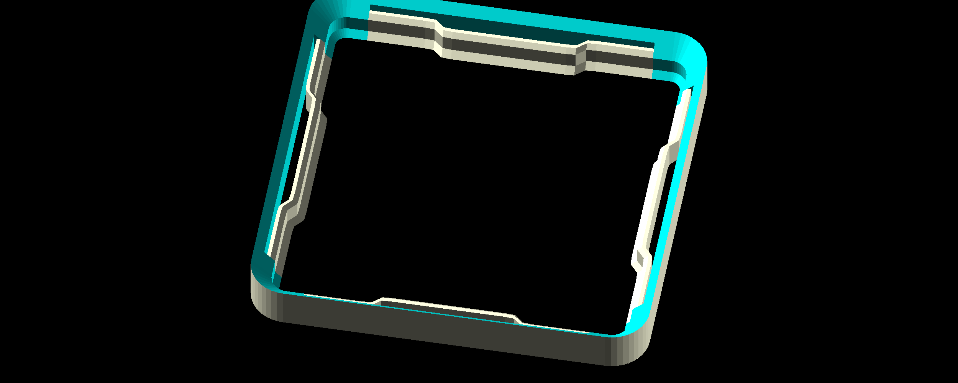
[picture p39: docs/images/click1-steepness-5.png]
Click latch with click1_steepness=5


## Filler

If the baseplate is not a multiple of 42mm, there's some room that can't be used for a full-sized cell. There are different options for what to do with this space.

The filler algorithm can be configured with the `filler_x` and `filler_y` properties.

### None

In `None` mode, the remaining space is simply filled with padding.

<!-- openscad -o docs/images/filler-none.png --camera=0,0,0,40,0,10,150 -D plate_size='[71, 42]' -D filler_x=0 -->
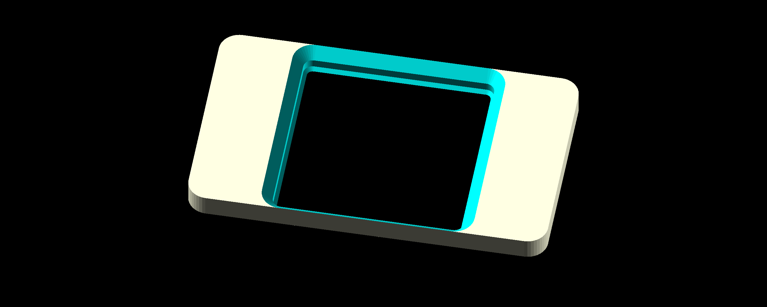
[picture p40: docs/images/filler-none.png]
No filler


### Integer Fraction

In `Integer Fraction` mode, the remaining space is filled with reduced-size cells that are an integer fraction of the standard cell size. This is the default, configured to use half-size cells.

<!-- openscad -o docs/images/filler-half.png --camera=0,0,0,40,0,10,150 -D plate_size='[71, 42]' -D filler_x=1 -->
Half-cell filler

> [!NOTE]
> The old `do_half_x` and `do_half_y` options have been removed.

You can change the fraction using the `filler_fraction` option, for example the value "3" for one-third size cells:

<!-- openscad -o docs/images/filler-third.png --camera=0,0,0,40,0,10,150 -D plate_size='[71, 42]' -D filler_x=1 -D filler_fraction=[3,3] -->
Third-cell filler

### Dynamic

In `Dynamic` mode, the remaining space is used up completely by a flexibly size cell.

<!-- openscad -o docs/images/filler-dynamic.png --camera=0,0,0,40,0,10,150 -D plate_size='[71, 42]' -D filler_x=2 -->
Dynamic filler

Note that there is a minimum size of the dynamic filler cell, configured by `filler_minimum_size`. This ensures that the filler does not become so small that the geometry breaks. If the cell is too small, it will be added to the last cell instead, creating a cell that is slightly bigger than 42mm:

<!-- openscad -o docs/images/filler-dynamic-expand.png --camera=0,0,0,40,0,10,150 -D plate_size='[88, 42]' -D filler_x=2 -->
Dynamic filler expanded

If you wish to only create larger cells, not smaller cells, you can set the minimum size to 42:

<!-- openscad -o docs/images/filler-dynamic-expand-always.png --camera=0,0,0,40,0,10,150 -D plate_size='[120, 42]' -D filler_x=2 -D filler_minimum_size=[42,42] -->
Dynamic filler always expanded

## Lightweight

`hollow` skeletonizes the baseplate: instead of solid material between the cells, only a thin wall following the Gridfinity profile is printed. Neighbouring cells share a hollow channel, open towards the bed and closed at the top by a self-supporting 45° roof. Without magnets this roughly halves filament use and print time — a 4x4 plate drops from 20.6cm³ to 10.5cm³.

<!-- openscad -o docs/images/lightweight.png --camera=0,0,0,150,0,25,260 -D plate_size='[84, 84]' -D hollow=true -D connector_intersection_puzzle=false -D numbering=false -->
Lightweight baseplate, seen from below

The same plate without `hollow`, also seen from below:

<!-- openscad -o docs/images/lightweight-off.png --camera=0,0,0,150,0,25,260 -D plate_size='[84, 84]' -D hollow=false -D connector_intersection_puzzle=false -D numbering=false -->
Standard baseplate, seen from below

The top surface, the outer wall of each segment and the puzzle connectors stay solid, so segments link up the same way and the plate looks unchanged from above.

> [!NOTE]
> Hollow mode is incompatible with magnets, `solid_base` and the click latch — there is no material left to hold them, and GridFlock refuses to render that combination.

### Wall thickness

`hollow_wall` sets the wall thickness. It is a *horizontal* thickness, which is what the slicer sees on each layer, so setting it to your nozzle diameter prints the plate as a single wall with no infill. The default 0.8mm is one wall on a 0.8mm nozzle, two to three on a 0.4mm nozzle.

<!-- openscad -o docs/images/lightweight-wall.png --camera=0,0,0,150,0,25,260 -D plate_size='[84, 84]' -D hollow=true -D hollow_wall=1.6 -D connector_intersection_puzzle=false -D numbering=false -->
Lightweight baseplate with thicker walls

### Connector fill

`hollow_connector_fill` keeps that much solid material around every puzzle connector, male and female. Setting it to 0 saves that material, but leaves the connectors weaker.

<!-- openscad -o docs/images/connector-fill.png --camera=0,0,0,180,0,0,60 -D plate_size='[84, 84]' -D bed_size='[60, 100]' -D hollow=true -D numbering=false -->
Intersection puzzle connectors with connector fill, seen from below

The same connectors with `hollow_connector_fill=0`:

<!-- openscad -o docs/images/connector-fill-off.png --camera=0,0,0,180,0,0,60 -D plate_size='[84, 84]' -D bed_size='[60, 100]' -D hollow=true -D hollow_connector_fill=0 -D numbering=false -->
Intersection puzzle connectors without connector fill, seen from below

### Bottom lip

The Gridfinity profile ends in a 0.7mm lip that slopes back inwards. It is not functionally required; `remove_bottom_lip` replaces it with a straight continuation of the vertical section. This saves a little filament, removes the overhang where two cells meet, and gives the first layer a flat contact area instead of a knife edge.

<!-- openscad -o docs/images/bottom-lip.png --camera=0,0,0,150,0,25,140 -D plate_size='[42, 42]' -D remove_bottom_lip=true -D connector_intersection_puzzle=false -D numbering=false -->
Baseplate with the bottom lip removed

It can be used on its own, and is always enabled in hollow mode, where the inward slope would taper the horizontally measured walls to nothing at the first layer.

## Corner radius

GridFlock generates plates with a corner radius of 4mm by default. This matches the Gridfinity corner radius, so when the plate size is a perfect multiple of 42, there is no gap.

<!-- openscad -o docs/images/corner-radius.png --camera=0,0,0,40,0,10,100 -D plate_size='[42, 42]' -D magnets=false -->
Corner radius

You can configure the radius with the `plate_corner_radius` property, e.g. 1mm:

<!-- openscad -o docs/images/corner-radius-1.png --camera=0,0,0,40,0,10,100 -D plate_size='[42, 42]' -D magnets=false -D plate_corner_radius=1 -->
Corner radius 1mm

## Alignment

When the plate size is not a clean multiple of 42mm, the grid is centered by default. You can adjust this using the `alignment` option, which can be configured for each axis. A value of 0.5 will center the grid (the default):

<!-- openscad -o docs/images/align-center.png --camera=0,0,0,40,0,10,200 -D plate_size='[62, 62]' -D magnets=false -->
Center alignment

A lower value will shift the grid to the west/south direction:

<!-- openscad -o docs/images/align-west.png --camera=0,0,0,40,0,10,200 -D plate_size='[62, 62]' -D magnets=false -D alignment='[0,0.2]' -->
West alignment

A higher value will shift the grid to the east/north direction:

<!-- openscad -o docs/images/align-east.png --camera=0,0,0,40,0,10,200 -D plate_size='[62, 62]' -D magnets=false -D alignment='[0.8,1]' -->
East alignment

The plate size remains unchanged.

## Custom cell size

GridFlock uses Gridfinity Rebuilt under the hood. Grid dimensions are not hard-coded, so in principle it is possible to use GridFlock with a custom cell size. This is not tested and not exposed in the online generator.

<!-- openscad -o docs/images/custom-cell.png --camera=0,0,0,40,0,10,300 -D plate_size='[100, 100]' -D BASEPLATE_DIMENSIONS='[50, 33]' -D magnets=true -->
Custom cell configuration

## Solid base

For added stability, you can add a solid base to the grid plate using the `solid_base` option.

<!-- openscad -o docs/images/solid_base.png --camera=0,0,0,40,0,10,200 -D plate_size='[105, 63]' -D magnets=false -D solid_base=5 -->
Thumb screw with solid base

## Bottom Chamfer

You can add a chamfer to the edge of the plate using the `bottom_chamfer` option.

<!-- openscad -o docs/images/bottom-chamfer.png --camera=0,0,0,140,0,10,200 -D plate_size='[105, 63]' -D 'bed_size=[70, 70]' -D magnets=false -D bottom_chamfer='[1.5, 1.5, 1.5, 1.5]' -->
Bottom chamfer

## Top Chamfer

Similarly, you can add a `top_chamfer` option.

<!-- openscad -o docs/images/top-chamfer.png --camera=0,0,0,40,0,10,200 -D plate_size='[105, 63]' -D 'bed_size=[70, 70]' -D magnets=false -D top_chamfer='[1.5, 1.5, 1.5, 1.5]' -->
Top chamfer

## Numbering

The number of each segment is embossed on the bottom of the segment to simplify assembly.

The depth of the embossing can be configured with `number_depth`. The size can be configured with `number_size`. The font can be configured with `number_font`.

<!-- openscad -o docs/images/numbering.png --camera=0,0,0,140,0,10,300 -D plate_size='[168, 168]' -D bed_size='[100,100]' -D magnets=false -->
Numbering from below

### Squeezed number

In rare cases, GridFlock may produce a segment that is only one cell wide, which leaves less room for the embossing. In that case, the smaller `number_squeeze_size` is used.

<!-- openscad -o docs/images/numbering-squeeze.png --camera=0,0,0,140,0,10,200 -D plate_size='[84, 84]' -D bed_size='[60,100]' -D magnets=false -->
Squeezed numbering

## Plate Wall

The plate wall is an additional rim around the final plate. It can extend up and/or down. The thickness of the wall can be configured for each side using the `plate_wall_thickness` option. 

### Top plate wall

A top wall can be used to keep your bins from slipping off the plate.

<!-- openscad -o docs/images/wall-top.png --camera=0,0,0,40,0,20,200 -D plate_size='[84, 84]' -D magnets=false -D plate_wall_thickness='[1,1,1,1]' -D plate_wall_height='[5,0]' -->
Top wall

### Bottom plate wall

A bottom wall can be used to keep your grid from slipping off e.g. a table, without requiring glue or screws to fix the grid in place.

> [!TIP]
> A bottom wall must be printed upside down. Use a brim to ensure bed adhesion. Magnets, solid base and other features may not be possible without supports.

<!-- openscad -o docs/images/wall-bottom.png --camera=0,0,0,140,0,20,200 -D plate_size='[84, 84]' -D magnets=false -D plate_wall_thickness='[1,1,1,1]' -D plate_wall_height='[0,5]' -->
Bottom wall

### Variable wall height

The top and bottom wall height can also be adjusted individually for each corner using the `plate_wall_below` and `plate_wall_above` options. This allows you to create shelf-style grids. The following example has a plate wall thickness of 1mm on all sides except south, and a variable height of 20mm for the NW and NE corners.

<!-- openscad -o docs/images/wall-variable.png --camera=0,0,0,40,0,20,300 -D plate_size='[84, 84]' -D plate_wall_thickness='[1,1,0,1]' -D plate_wall_above='[0, 20, 20, 0]' -->
Shelf

> [!NOTE]
> Variable height does not currently render correctly with segmented baseplates.

## openGrid Adapter

**[Customizer with recommended openConnect layout](https://gridflock.yawk.at/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)**

You can use GridFlock to generate Gridfinity "shelves" that can be attached to an [openGrid](https://www.opengrid.world/) system. Configure a plate wall of sufficient height, and then enable `adapter_north`, `adapter_east`, `adapter_west`, or `adapter_south`. For example, the following shelf has been generated with `plate_wall_thickness=[0,1,1,1]` (1mm wall everywhere except north) and `plate_wall_above=[20,0,0,20]` (20mm wall at south-east and south-west corners):

<!-- openscad -o docs/images/adapter-simple.png --camera=0,0,0,60,0,20,100 -D plate_size='[42, 42]' -D adapter_south=true -D adapter_mode=6 -D plate_wall_thickness='[0,1,1,1]' -D plate_wall_above='[20,0,0,20]' -->
Shelf

Note that openConnect is preferred over directly printing openGrid snaps, see below.

The wall will automatically be filled with as many adapters as possible:

<!-- openscad -o docs/images/adapter-multi.png --camera=0,0,0,60,0,20,100 -D plate_size='[88, 42]' -D adapter_south=true -D adapter_mode=6 -D plate_wall_thickness='[0,1,1,1]' -D plate_wall_above='[20,0,0,20]' -->
Shelf

> [!NOTE]
> Adapters do not render correctly with segmented baseplates.

### Adapter types

GridFlock offers various adapter variants.

#### Standard openGrid

You can print the standard openGrid connector directly onto the wall. Normal and lite, directional and non-directional variants are available. There is also a "vertical" variant of each which cuts a 45° angle from the bottom of each connector which makes printing without supports possible, but reduces strength.

> [!NOTE]
> The printability vs strength tradeoff is substantial with this adapter. The vertical variants don't stay in place nearly as well, but the non-vertical type is very difficult to print. The openConnect system described below is the preferred option for connecting to openGrid.

The standard connector works with standard openGrid plates, but not lite plates:

<!-- openscad -o docs/images/opengrid-standard.png --camera=0,0,0,60,0,20,100 -D plate_size='[42, 42]' -D adapter_south=true -D adapter_mode=0 -D plate_wall_thickness='[0,1,1,1]' -D plate_wall_above='[20,0,0,20]' -->
Standard connector

The lite connector works with all openGrid plates, but has reduced strength:

<!-- openscad -o docs/images/opengrid-lite.png --camera=0,0,0,60,0,20,100 -D plate_size='[42, 42]' -D adapter_south=true -D adapter_mode=1 -D plate_wall_thickness='[0,1,1,1]' -D plate_wall_above='[20,0,0,20]' -->
Lite connector

The directional connector has increased strength:

<!-- openscad -o docs/images/opengrid-directional.png --camera=0,0,0,60,0,20,100 -D plate_size='[42, 42]' -D adapter_south=true -D adapter_mode=2 -D plate_wall_thickness='[0,1,1,1]' -D plate_wall_above='[20,0,0,20]' -->
Directional connector

The vertical variants make the connector actually printable:

<!-- openscad -o docs/images/opengrid-vertical.png --camera=0,0,0,60,0,20,100 -D plate_size='[42, 42]' -D adapter_south=true -D adapter_mode=4 -D plate_wall_thickness='[0,1,1,1]' -D plate_wall_above='[20,0,0,20]' -->
Vertical connector

#### openConnect

[openConnect](https://www.printables.com/model/1559478-openconnect-opengrids-own-connector-system) is a system that adds a separately printed connector in between GridFlock and openGrid. This makes vertical printing a breeze without compromising attachment strength.

Since the GridFlock side of the connector is recessed, this requires a thicker wall of ~4mm, but vertical height can be lower.

<!-- openscad -o docs/images/openconnect-standard.png --camera=0,0,0,60,0,20,100 -D plate_size='[42, 42]' -D adapter_south=true -D adapter_mode=10 -D plate_wall_thickness='[0,1,4,1]' -D plate_wall_above='[14,0,0,14]' -->
Standard openConnect

There is also a "lock" variant that increases the connection strength to the openConnect interconnect. This connection is so strong that you may need a hammer to install the interconnect. This is my preferred option.

## Intersection Holes

Holes can be added at cell intersections. By default, these are vertical screw holes that can be used to screw down the plate. Alternatively, they can be [magnet pockets](#intersection-magnets) that hold the plate on a metal surface. The holes can be placed at various positions depending on use case, see [hole locations](#hole-locations).

<!-- openscad -o docs/images/vscrews.png --camera=0,0,0,40,0,10,400 -D plate_size='[336, 210]' -D 'bed_size=[180, 250]' -D magnets=false -D vertical_screw_plate_corners=true -D vertical_screw_segment_corners=true -D vertical_screw_other=true -->
Vertical screws

### Screw dimensions

The screw diameter can be configured with `vertical_screw_diameter`.

<!-- openscad -o docs/images/vscrews-diameter.png --camera=0,0,0,40,0,10,200 -D plate_size='[105, 63]' -D magnets=false -D vertical_screw_other=true -D vertical_screw_segment_corners=true -D vertical_screw_plate_corners=true -D vertical_screw_diameter=2 -->
Vertical screw diameter

GridFlock can also make space for countersunk screws. The dimensions of the countersunk head should be specified using `vertical_screw_countersink_top`. The first value of this vector is the diameter of the head, and the second value the height of the head until the screw shaft. The below example uses `[6, 2.5]`, which are typical dimensions for an M3 countersunk screw.

<!-- openscad -o docs/images/vscrews-countersink.png --camera=0,0,0,40,0,10,200 -D plate_size='[105, 63]' -D magnets=false -D vertical_screw_other=true -D vertical_screw_segment_corners=true -D vertical_screw_plate_corners=true -D vertical_screw_countersink_top='[6, 2.5]' -->
Vertical screw countersunk

A similar option exists for a counterbore recess.

<!-- openscad -o docs/images/vscrews-counterbore.png --camera=0,0,0,40,0,10,200 -D plate_size='[105, 63]' -D magnets=false -D vertical_screw_other=true -D vertical_screw_segment_corners=true -D vertical_screw_plate_corners=true -D vertical_screw_counterbore_top='[6, 2.5]' -->
Vertical screw counterbore

If you combine the two options, the counterbore slot is placed above the countersink slot. You can use this to recess the countersunk head into the grid, to avoid interfering with the wider part of a bin.

<!-- openscad -o docs/images/vscrews-counterboth.png --camera=0,0,0,30,0,10,200 -D plate_size='[105, 63]' -D magnets=false -D vertical_screw_other=true -D vertical_screw_segment_corners=true -D vertical_screw_plate_corners=true -D solid_base=5 -D vertical_screw_counterbore_top='[6, 4]' -D vertical_screw_countersink_top='[6, 2.5]' -->
Vertical screw counterbore + countersunk

### Intersection magnets

Setting `vertical_screw_style` to `Magnet` replaces the screw holes with magnet pockets on the bottom of the plate. These magnets hold the plate itself in place on a metal surface, such as a steel drawer. They are independent of the [bin magnets](#magnets) described above.

<!-- openscad -o docs/images/vmagnets.png --camera=0,0,0,140,0,10,230 -D plate_size='[168, 84]' -D magnets=false -D vertical_screw_style=1 -D vertical_screw_plate_corners=true -D vertical_screw_other=true -->
Intersection magnets

By default, the pockets are open at the bottom. The magnets can be glued in, or press-fit by tuning `vertical_screw_magnet_diameter`. Even loose magnets will keep the plate from sliding around, but they won't hold the plate in place when it's lifted. See [magnet floor](#magnet-floor) for alternatives.

The magnets use the same [locations](#hole-locations) as screws. Note that intersections on the plate edge often have no room for a magnet, and intersections on segment edges interfere with the intersection puzzle connector.

#### Magnet dimensions

The pocket size is configured with `vertical_screw_magnet_diameter` and `vertical_screw_magnet_height`. The defaults fit standard 6x2mm magnets.

#### Magnet floor

`vertical_screw_magnet_floor` adds a floor below the pocket, which keeps the magnets in the plate without glue. A value of 0.25mm or one or two layers is enough. A floor reduces the magnet strength a bit, because the magnet is further away from the metal surface.

With a floor, the pocket is fully enclosed, so you have to pause the print at the top of the pocket to insert the magnets. Alternatively, you can set `vertical_screw_magnet_height` to a value larger than the plate height (e.g. 10). The pocket then extends all the way through the plate, and the magnets can be pushed in from the top after printing:

<!-- openscad -o docs/images/vmagnets-open-top.png --camera=21,0,0,40,0,10,100 -D plate_size='[126, 84]' -D magnets=false -D vertical_screw_style=1 -D vertical_screw_plate_corners=true -D vertical_screw_magnet_floor=0.25 -D vertical_screw_magnet_height=10 -->
Intersection magnets inserted from the top

> [!NOTE]
> The hole cuts into the corners of the gridfinity profile a bit. This should not matter for most bins.

#### Magnet release hole

A small hole goes through the whole plate at each magnet pocket. It lets you push the magnet out with a needle: through the top for pockets that are open at the bottom, or through the floor for pockets that are open at the top. The diameter is configured with `vertical_screw_magnet_release_diameter`, and setting it to 0 disables the hole.

<!-- openscad -o docs/images/vmagnets-release.png --camera=21,0,0,140,0,10,60 -D plate_size='[126, 84]' -D magnets=false -D vertical_screw_style=1 -D vertical_screw_plate_corners=true -->
Magnet release hole

### Hole locations

During the generation process, each intersection is classified into one of five categories. Each of these categories can have holes enabled separately.

#### Plate corners

Setting `vertical_screw_plate_corners` enables screws at _plate_ corners (not _segment_!). By default, the plate corner is at the intersection that is one cell away from the plate edge.

<!-- openscad -o docs/images/vscrews-plate-corners.png --camera=0,0,0,40,0,10,400 -D plate_size='[336, 210]' -D 'bed_size=[180, 250]' -D magnets=false -D vertical_screw_plate_corners=true -->
Vertical screws at plate corners

Using the `vertical_screw_plate_corner_inset` property (default 1,1), a different intersection can be selected as the plate corner. In the below example, the property has been set to `[1,2]`, which selects the second intersection in the y direction as the plate corner, instead of the first.

<!-- openscad -o docs/images/vscrews-plate-corners-mod.png --camera=0,0,0,40,0,10,400 -D plate_size='[336, 210]' -D 'bed_size=[180, 250]' -D magnets=false -D vertical_screw_plate_corners=true -D vertical_screw_plate_corner_inset='[1,2]' -->
Vertical screws at plate corners

#### Plate edges

Setting `vertical_screw_plate_edges` enables screws at _plate_ edges. These edges often don't have room for a screw, but if there's padding, it might work.

<!-- openscad -o docs/images/vscrews-plate-edges.png --camera=0,0,0,40,0,10,400 -D plate_size='[346, 220]' -D 'bed_size=[180, 250]' -D magnets=false -D vertical_screw_plate_edges=true -->
Vertical screws at plate edges

#### Segment corners

Setting `vertical_screw_segment_corners` enables screws at _segment_ corners. Similar to plate corners, the exact behavior can be configured using the `vertical_screw_segment_corner_inset` property.

> [!NOTE]
> In the below example, some of the segment corners are also plate corners. `vertical_screw_plate_corners` is disabled, so those intersections do not get a screw hole. You can enable both properties if you want screw holes in all segment corners.

<!-- openscad -o docs/images/vscrews-segment-corners.png --camera=0,0,0,40,0,10,400 -D plate_size='[336, 210]' -D 'bed_size=[180, 250]' -D magnets=false -D vertical_screw_segment_corners=true -->
Vertical screws at segment corners

#### Segment edges

Setting `vertical_screw_segment_edges` enables screws at _segment_ edges. This can interfere with the intersection puzzle connector, so this combination is not recommended.

<!-- openscad -o docs/images/vscrews-segment-edges.png --camera=0,0,0,40,0,10,400 -D plate_size='[336, 210]' -D 'bed_size=[180, 250]' -D magnets=false -D vertical_screw_segment_edges=true  -D connector_intersection_puzzle=false -D connector_edge_puzzle=true -->
Vertical screws at segment edges

#### Other intersections

Any intersections that do not fall under the above criteria can be configured using the `vertical_screw_other` setting.

<!-- openscad -o docs/images/vscrews-else.png --camera=0,0,0,40,0,10,400 -D plate_size='[336, 210]' -D 'bed_size=[180, 250]' -D magnets=false -D vertical_screw_other=true -->
Vertical screws at other locations

#### Combined

Vertical screw locations can be combined as needed. A common combination would be `vertical_screw_plate_corners`, `vertical_screw_segment_corners` and `vertical_screw_other`, which only leaves the segment edges without screws.

<!-- openscad -o docs/images/vscrews-most.png --camera=0,0,0,40,0,10,400 -D plate_size='[336, 210]' -D 'bed_size=[180, 250]' -D magnets=false -D vertical_screw_other=true -D vertical_screw_segment_corners=true -D vertical_screw_plate_corners=true -->
Vertical screws at most locations

## Horizontal Screws

Horizontal screws are used to attach the plate on the side. Enable screws for individual edges with the `horizontal_screw_wall_north`, `horizontal_screw_wall_east`, `horizontal_screw_wall_south`, and `horizontal_screw_wall_west` options. The screws will be placed in the middle of each cell.

<!-- openscad -o docs/images/hscrews.png --camera=0,0,0,40,0,10,400 -D plate_size='[84, 84]' -D plate_wall_thickness='[3, 0, 0, 0]' -D plate_wall_height='[5, 0]' -D horizontal_screw_wall_north=true -->
Horizontal screws

Similar to vertical screws, the screw head can be customized with `horizontal_screw_countersink_top` and `horizontal_screw_counterbore_top`. 

The exact hole position can be adjusted using `horizontal_screw_offset`. By default, the hole will be centered vertically on the plate or any wall.

## Thumb Screw

[Gridfinity Refined](https://www.printables.com/model/413761-gridfinity-refined) has a thumb screw design to screw bins securely into base plates. GridFlock can generate a compatible thumb screw hole with the `thumbscrews` option.

<!-- openscad -o docs/images/thumb-screw-magnet.png --camera=0,0,0,40,0,10,200 -D plate_size='[105, 63]' -D magnets=true -D magnet_style=0 -D magnet_frame_style=0 -D thumbscrews=true -->
Thumb screw with solid magnet frame

Note that in order to add a thumb screw hole, there must be something to cut the hole out of. In the above example, that is a solid frame magnet. Alternatively, you can also use a `solid_base`:

<!-- openscad -o docs/images/thumb-screw-base.png --camera=0,0,0,40,0,10,200 -D plate_size='[105, 63]' -D magnets=false -D solid_base=5 -D thumbscrews=true -->
Thumb screw with solid base

Or you can use press-fit magnets with a solid base:

<!-- openscad -o docs/images/thumb-screw-base-magnet.png --camera=0,0,0,40,0,10,200 -D plate_size='[105, 63]' -D magnets=true -D solid_base=5 -D thumbscrews=true -->
Thumb screw with solid base and press-fit magnets

For the last option, a longer screw design is required, for example the stackable screw design from Gridfinity Refined.

## Segmentation

To produce models that fit the print bed, GridFlock splits the baseplate into _segments_. The segmentation algorithms compromise between different priorities in segment sizing.

The base plate is first split along the x axis (horizontally) and those pieces are further split along the y axis (vertically).

### Horizontal

Along the x axis, the plate is split into roughly equally sized segments by default. This is called the "ideal" algorithm.

<!-- openscad -o docs/images/segment-x-ideal.png --camera=0,0,0,40,0,10,400 -D plate_size='[252, 84]' -D bed_size='[180, 180]' -D magnets=false -D connector_intersection_puzzle=false -->
Ideal segmentation algorithm

With the `x_segment_algorithm` property, you can also select the "incremental" algorithm. With this algorithm, the plate is split into pieces that are as large as possible, and the last piece is sized to use the remaining space. In this example, the printer can print four cells at a time, so the first segment is four cells wide:

<!-- openscad -o docs/images/segment-x-incremental.png --camera=0,0,0,40,0,10,400 -D plate_size='[252, 84]' -D bed_size='[180, 180]' -D magnets=false -D connector_intersection_puzzle=false -D x_segment_algorithm=1 -->
Incremental segmentation algorithm

When using the incremental algorithm, you can also override the size of the first segment using the `x_column_count_first` property.

<!-- openscad -o docs/images/segment-x-incremental-override.png --camera=0,0,0,40,0,10,400 -D plate_size='[252, 84]' -D bed_size='[180, 180]' -D magnets=false -D connector_intersection_puzzle=false -D x_segment_algorithm=1 -D x_column_count_first=1 -->
Incremental segmentation alogirthm with cell count override (x splitting)

Note that the incremental algorithm has a few extra constraints, such as forbidding a last segment without cells. These constraints are satisfied by shrinking the first segment, so the first segment may not be the maximum size in all cases.

### Vertical

Vertical splitting is more complicated. The goal here is to avoid intersections where four segments meet at a corner. For this reason, there are actually two different segmentations on the y direction, which alternate. These segmentations never have a separation at the same position (they are _staggered_).

Both segmentations are planned using the incremental algorithm described above, with some adjustments to avoid single-cell segments where possible.

<!-- openscad -o docs/images/segment-y.png --camera=0,0,0,40,0,10,600 -D plate_size='[84, 252]' -D bed_size='[50, 180]' -D magnets=false -D connector_intersection_puzzle=false -->
Y axis segementation

You can override the cell count for the first segment of each plan using the `y_row_count_first` property.

<!-- openscad -o docs/images/segment-y-override.png --camera=0,0,0,40,0,10,600 -D plate_size='[84, 252]' -D bed_size='[50, 180]' -D magnets=false -D connector_intersection_puzzle=false -D y_row_count_first='[1, 1]' -->
Incremental segmentation alogirthm with cell count override (y splitting)

### Separate edge padding

By default, positive edge padding is attached to the outer baseplate segments. Enable `separate_edge_padding` to generate positive edge padding as separate printable strips instead. The strips are planned as normal segments, so they include the connectors needed to attach them to the neighboring baseplate segments. Note that if the padding is small, connectors may not fully fit.

<!-- openscad -o docs/images/separate-edge.png --camera=0,0,0,40,0,10,600 -D plate_size='[180, 180]' -D bed_size='[100, 100]' -D connector_intersection_puzzle=true -D separate_edge_padding=true -->
Separate edge padding

## Edge Adjustment

The basic GridFlock cell placement algorithm is simple: Fit as many cells into the configured `plate_size`, and evenly distribute any remaining space as padding along the edges.

<!-- openscad -o docs/images/edge-adjustment-default.png --camera=0,0,0,40,0,10,400 -D plate_size='[104, 104]' -D magnets=false -->
Default edge adjustment

In some cases, you may want to modify this behavior using the `edge_adjust` property. This property is added to the padding on each of the four sides _after_ the cell placement calculation.

> [!NOTE]
> Because the edge adjustment is added to the padding, it will add or remove from the final plate size!

### Shifting the grid

> [!NOTE]
> It is easier to use the alignment option for this.

You may want to move the generated grid so that it is not centered on the plate. In the below example, I've shifted the grid 5mm to the north and 10mm to the east using `edge_adjust=[-5, -10, 5, 10]` Note that the adjustment values for east and west / north and south even out so that the final plate size remains unchanged.

<!-- openscad -o docs/images/edge-adjustment-shift.png --camera=0,0,0,40,0,10,400 -D plate_size='[104, 104]' -D magnets=false -D edge_adjust='[-5, -10, 5, 10]' -->
Shifting the grid using edge adjustment

### Adding empty space

If you do not want to generate grid cells on the full grid, you can use the edge adjustment to add padding. Below, the plate_size is `[42, 42]`, but `edge_adjust=[50, 0, 0, 0]` adds another 50mm space on the north side.

<!-- openscad -o docs/images/edge-adjustment-pad.png --camera=0,0,0,40,0,10,400 -D plate_size='[42, 42]' -D magnets=false -D edge_adjust='[50, 0, 0, 0]' -->
Adding padding using edge adjustment

### Squeezing in extra cells

If your plate is slightly too large for where you want to put it, but you don't want to lose any grid cells, you can use edge adjustment to cut off a bit. In the below example, a plate size of 84x84 is combined with `edge_adjust=[0, -2, 0, -2]`, cutting off 2mm on the east and west sides. The final plate is only 80mm wide.

<!-- openscad -o docs/images/edge-adjustment-cut.png --camera=0,0,0,40,0,20,300 -D plate_size='[84, 84]' -D magnets=false -D edge_adjust='[0, -2, 0, -2]' -->
Cutting the grid using edge adjustment

If you do this, you may of course have trouble fitting bins into the empty space.

## Top Slice

Using the `top_slice` option, you can cut off a bit of the top of the baseplate:

<!-- openscad -o docs/images/top-slice.png --camera=0,0,0,40,0,20,130 -D plate_size='[84, 42]' -D top_slice=0.5 -->
Top Slice

This can be useful when the baseplate is printed upside down, to increase contact area with the print bed.

## Stacked Print

In stacked print mode, segments are placed above each other with a slight gap in between. With the right print settings, this can allow you to print all the segments at once.

> [!WARNING]
> For very basic plates with no padding or filler cells stacked printing works well, but many features will result in overhangs that may be difficult to print.

<!-- openscad -o docs/images/stacked-print.png --camera=42,42,0,40,0,20,200 -D plate_size='[84, 126]' -D bed_size='[100,100]' -D stacked_print=true -->
Stacked print

### Segment Gap

Segments are placed on top of each other with a slight gap. The base of each segment is placed at a multiple of `stacked_print_layer_height`. The gap is at least `stacked_print_min_gap` high, but may be slightly larger to reach the next print layer.

> [!NOTE]
> The layer height has a big impact on print quality. A gap that is too small may make the segments inseperable, while a gap that is too large easily leads to print failures due to unsupported surfaces. A layer height of 0.2 with the default gap works in my testing.

The default `stacked_print_min_gap` is 0.5. That means that the gap between segments will be 0.5 to 1.5 layers:

<!-- openscad -o docs/images/stacked-print-gap-normal.png --camera=21,21,0,90,0,0,70 -D plate_size='[42, 42]' -D stacked_print=true -D stacked_print_duplicates=2 -->
Slight gap between segments

Here's an example with an exaggerated `stacked_print_min_gap` of 8 layers:

<!-- openscad -o docs/images/stacked-print-gap-exaggerated.png --camera=21,21,0,90,0,0,70 -D plate_size='[42, 42]' -D stacked_print=true -D stacked_print_duplicates=2 -D stacked_print_min_gap=8 -->
Slight gap between segments

### Duplicates

If you need multiple of the same baseplate, you can use the `stacked_print_duplicates` option to repeat each segment multiple times:

<!-- openscad -o docs/images/stacked-print-duplicate.png --camera=42,42,0,40,0,20,200 -D plate_size='[84, 126]' -D bed_size='[100,100]' -D stacked_print=true -D stacked_print_duplicates=3 -->
Duplicate stacked print

### Flipping

In order to reduce overhangs, segments are "flipped" and print on their heads. The bottom segment is not flipped by default. You can control this flipping behavior using the `stacked_print_flip` and `stacked_print_flip_first` options. Both options can be set to either not flip, flip east-to-west (rotate 180° around y axis), or flip north-to-south (rotate 180° around x axis).

### Top Slice

Enabling stacked print automatically _adds_ to the [top slice](#top-slice) to increase contact area. The value that is added is configurable through `stacked_print_slice`.

## Cell override

For really weird use cases, you can override the content of individual cells using the `cell_override` option. Due to openscad limitations, this option is a string. Each character corresponds to a particular override style. Cells are counted from west to east and then from south to north: For a 2x2 grid, the first character customizes the lower left (SW) cell, the second character the lower right (SE) cell, the third the upper left (NW) cell, and the last character the upper right (NE) cell.

### Normal cell

A character `c` produces a normal cell. The override string is `cccc`:

<!-- openscad -o docs/images/override-normal.png --camera=0,0,0,40,0,20,300 -D plate_size='[104, 104]' -D magnets=false -D 'cell_override="cccc"' -->
Normal cell override

### Solid

A character `s` produces a solid fill. The override string is `cssc`:

<!-- openscad -o docs/images/override-solid.png --camera=0,0,0,40,0,20,300 -D plate_size='[104, 104]' -D magnets=false -D 'cell_override="cssc"' -->
Solid cell override

### Empty

A character `s` produces an empty cell. The override string is `ceec`:

<!-- openscad -o docs/images/override-empty.png --camera=0,0,0,40,0,20,300 -D plate_size='[104, 104]' -D magnets=false -D 'cell_override="ceec"' -->
Empty cell override

### Irregular Shapes

The cell override feature can be used to create grids with irregular shapes. Let's say we want to create a plate with this shape:

<!-- openscad -o docs/images/irregular-base-shape.png --camera=0,0,0,40,0,20,600 -D mode=1 docs/irregular/irregular.scad -->
Base shape for the irregular plate

One way to do this is to cut a rectangular base plate with this shape, e.g. in the slicer. But if we do this with a regular base plate, we get this result:

<!-- openscad -o docs/images/irregular-no-override.png --camera=0,0,0,40,0,20,600 -D mode=2 docs/irregular/irregular.scad -->
Irregular plate with no cell override

With cell overrides, we can selectively fill some of the cells so that only the "full" cells remain.

<!-- openscad -o docs/images/irregular-override.png --camera=0,0,0,40,0,20,600 -D mode=3 docs/irregular/irregular.scad -->
Irregular plate with cell override

## Building from source

The source file cannot be immediately opened in OpenScad. There is a dependency on Gridfinity Rebuilt, and some polygons are loaded from SVG files.

1. Install [`just`](https://just.systems/) and [`uv`](https://docs.astral.sh/uv/)
2. Clone the repository
3. Initialize the git submodules
4. Run `just paths` to extract the puzzle connector paths from the SVG
5. Now you can open `gridflock.scad` using OpenScad (development build required)

## Why the name?

Since the segments lock together, I considered "GridLock", but that's not a googleable word. I added the F from "Gridfinity" to make the name unique. You can also consider the set of segments that this project generates a "flock".

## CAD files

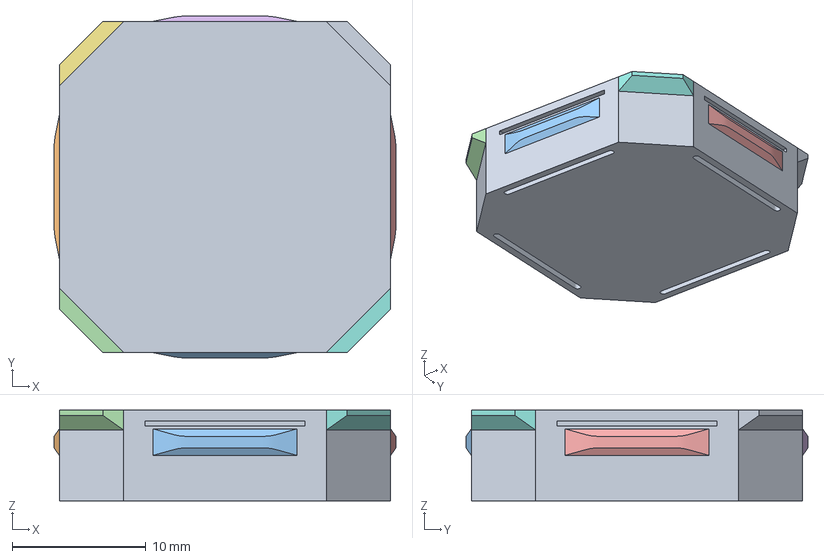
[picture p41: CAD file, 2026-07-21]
opengrid/opengrid-bare-snap.3mf
25.6 x 25.6 x 6.80 mm
Inner

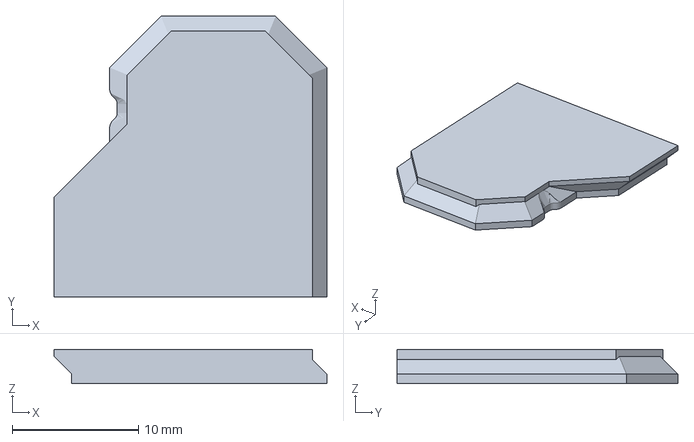
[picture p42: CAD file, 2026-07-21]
opengrid/openconnect_slot_negative_lock.3mf
21.6 x 22.2 x 2.70 mm

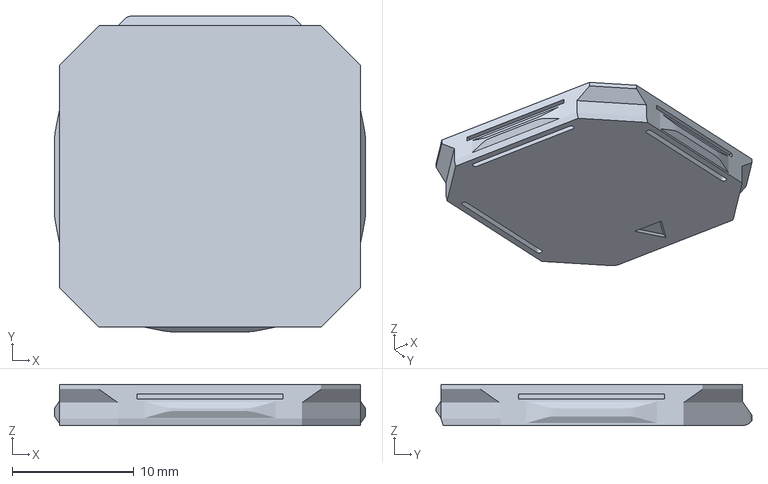
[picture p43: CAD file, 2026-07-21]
opengrid/opengrid-bare-directional-lite-snap-v2.3mf
25.6 x 26.0 x 3.40 mm

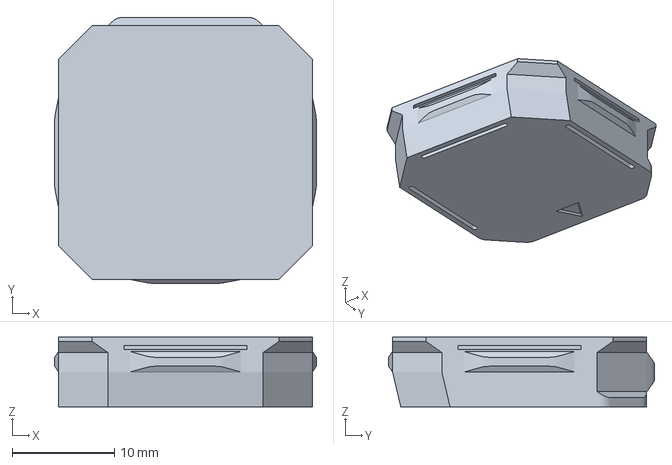
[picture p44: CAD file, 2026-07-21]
opengrid/opengrid-bare-directional-snap-v21.3mf
25.6 x 26.0 x 6.80 mm

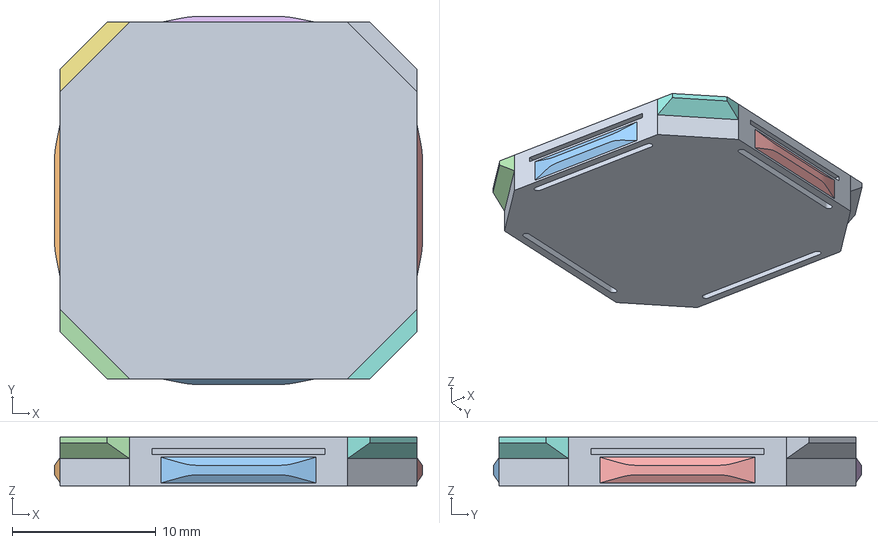
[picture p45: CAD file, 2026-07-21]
opengrid/opengrid-bare-lite-snap.3mf
25.6 x 25.6 x 3.40 mm
Inner

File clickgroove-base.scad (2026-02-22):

include <gridfinity-rebuilt-openscad/src/core/standard.scad>
use <gridfinity-rebuilt-openscad/src/core/bin.scad>
use <gridfinity-rebuilt-openscad/src/core/gridfinity-rebuilt-utility.scad>

$fn=50;

bin1 = new_bin(
    grid_size = [1, 1],
    height_mm = height(3, 0),
);

module click_groove() {
  height = 1.5;
  depth = height/2;
  gap = 0.1;
  translate([0, 2.15+0.25/2, 2.6]) rotate([0, 90, 0]) linear_extrude(30, center=true) polygon([[(1.8-height)/2-gap, -gap], [0.9, depth], [1.8-(1.8-height)/2+gap, -gap]]);
}

module draw_clickgroove_base() {
    difference() {
        bin_render(bin1);

        translate([0, -GRID_DIMENSIONS_MM.y/2]) click_groove();
        translate([0, GRID_DIMENSIONS_MM.y/2]) rotate([0, 0, 180]) click_groove();
        translate([-GRID_DIMENSIONS_MM.x/2, 0]) rotate([0, 0, -90]) click_groove();
        translate([GRID_DIMENSIONS_MM.x/2, 0]) rotate([0, 0, 90]) click_groove();
    }
}

draw_clickgroove_base();

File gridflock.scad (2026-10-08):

include <gridfinity-rebuilt-openscad/src/core/gridfinity-baseplate.scad>
use <gridfinity-rebuilt-openscad/src/helpers/list.scad>
include <paths/puzzle.scad>

// The size of the grid plate to generate
plate_size = [371, 254];
// The bed size of the printer, e.g. 250x220 for the Prusa Core One
bed_size = [250, 220];

/* [Magnets] */

// Whether to enable friction-fit magnets for each grid cell
magnets = false;
// Magnet style
magnet_style = 1; // [0:Glue from top, 1:Press-Fit, 2:Glue from bottom]
// Style of the magnet level
magnet_frame_style = 1; // [0:Solid (incompatible with press-fit), 1:Round Corners]
// Diameter of the magnet slot
magnet_diameter = 5.9; // 0.01
// Height of the magnet slot
magnet_height = 2.25; // 0.25
// Wall above the magnet. Should be small for maximum magnet strength
magnet_top = 0.5; // 0.25
// Floor below the magnet. Not structurally important, should be small to minimize filament use
magnet_bottom = 0.75; // 0.25
// Horizontal strength of the frame holding the magnet in place
magnet_border = 2; // 0.5
// Width of the magnet release slot
magnet_release_width = 3; // 0.5

/* [Click Latch (Experimental)] */

// Enable the click latch. WARNING: The plastic can deform over time, do not use PLA! PETG might be fine, but there are no long-term tests yet
click = false;
// Style of the click latch. The traditional arc style is more robust. The newer ClickGroove design can reduce creep when used with compatible bins, but still supports standard bins.
click_style = 1; // [0:Arc, 1:ClickGroove]

// Distance that the click latch extends into the bin area
click1_distance = 1; // .1
// Steepness of the click latch arc
click1_steepness = 1; // .1
// Length of the full click latch
click1_outer_length = 30;
// Length of the straight piece in the middle of the click latch. The arced pieces take up the remaining space
click1_inner_length = 0;
// Height of the click latch
click1_height = 3; // .1
// Thickness of the click latch. This is measured from the bottom of the baseplate profile
click1_strength = 1.6; // .1
// Thickness of the non-bending wall behind the click latch. This wall provides stability and prevents the click latch from bending too far
click1_wall_strength = 1; // .1

// Length of the gap behind the click latch
clickgroove_gap_length = 25;
// Length of the tab that engages with the bin groove
clickgroove_tab_length = 10;
// Thickness of the click latch. This is measured from the bottom of the baseplate profile
clickgroove_strength = 1.4; // .1
// Thickness of the non-bending wall behind the click latch. This wall provides stability and prevents the click latch from bending too far
clickgroove_wall_strength = 1; // .1
// How far the tab protudes from the normal baseplate profile. Increasing this produces a more secure fit
clickgroove_depth = 0.9; // .05

/* [Intersection Puzzle Connector] */

// Enable the intersection puzzle plate connector. This is similar to GridPlates/GRIPS. Small puzzle connectors are added cell intersections.
connector_intersection_puzzle = true;
// A value from 0 to 1 to modify the fit of the intersection puzzle connector. 0 is a loose fit, 1 is a tight fit.
intersection_puzzle_fit = 1; // [0:0.1:1]

/* [Edge Puzzle Connector] */

// Enable the edge puzzle plate connector. This connector is a bit cleaner, but is harder to print, especially when magnets are disabled (not enough vertical space). It's also more customizable, so you can tune the fit to your printer.
connector_edge_puzzle = false;

// Number of puzzle connectors per cell
edge_puzzle_count = 1;
// Dimensions of the male puzzle connector (main piece)
edge_puzzle_dim = [10, 2.5]; // 0.1
// Dimensions of the male puzzle connector (bridge to plate)
edge_puzzle_dim_c = [3, 1.2]; // 0.1
// Clearance of the puzzle connector. The female side is larger than the above dimensions by this amount
edge_puzzle_gap = 0.15; // 0.05
// If magnets are enabled, use the vertical space to add a border to the female puzzle socket, for added stability and better printability
edge_puzzle_magnet_border = true;
// Size of the added border
edge_puzzle_magnet_border_width = 2.5; // 0.1
// Height of the edge puzzle connector (female side, male is smaller by edge_puzzle_height_male_delta). You can set this to the full height, but make sure that no pieces of the segment remain unconnected!
edge_puzzle_height_female = 2.25; // 0.25
// Male side of the edge puzzle connector is smaller than the female side by this amount
edge_puzzle_height_male_delta = 0.25; // 0.25

/* [Filler] */

// When there is not enough room for a full cell, fill the remaining space with a half-width or dynamic width cell (x direction)
filler_x = 1; // [0:None, 1:Integer Fraction, 2:Dynamic]
// When there is not enough room for a full cell, fill the remaining space with a half-width or dynamic width cell (y direction)
filler_y = 1; // [0:None, 1:Integer Fraction, 2:Dynamic]
// Integer fraction of the reduced size cells, e.g. a value of 2 produces half-width cells, a value of 3 produces third-width cells
filler_fraction = [2, 2];
// Minimum size of filler cells in dynamic mode. If a filler cell would be smaller than this value, it is added to the previous cell instead, producing a cell that is larger than 42mm
filler_minimum_size = [15, 15];
// Padding alignment. The first value is the x direction (east/west), the second value the y direction (north/south). When padding is added to the build plate, this alignment is used to distribute it. A lower value will move the grid towards the west/south direction, adding more padding to the east/north
alignment = [0.5, 0.5]; // [0:0.1:1]

/* [Lightweight] */

// Skeletonize the baseplate: instead of solid material between the cells, only a thin wall following the gridfinity profile is printed. This roughly halves filament use and print time. Incompatible with magnets, a solid base and the click latch
hollow = false;
// Wall thickness in hollow mode. This is a horizontal thickness, which is what the slicer sees on each layer, so a value matching your nozzle diameter prints as a single wall
hollow_wall = 0.8; // 0.05
// Solid material kept around the puzzle connectors in hollow mode. Without it the connectors hang off a single wall with nothing behind them. 0 saves that material, at the cost of weaker connectors
hollow_connector_fill = 2; // 0.5
// Remove the bottom lip of the gridfinity profile, extending the vertical section of the profile straight down instead. The lip is not functionally required; removing it saves filament, removes the overhang between neighbouring cells, and widens the first layer. Always enabled in hollow mode
remove_bottom_lip = false;

/* [Numbering] */

// Enable numbering of the segements, embossed in a corner
numbering = true;
// Depth of the embossing
number_depth = 0.5; // 0.25
// Font size of the numbers
number_size = 3; // 0.5
// Font
number_font = "sans-serif";
// When a segment is very narrow, use this reduced number size. Should rarely be relevant
number_squeeze_size = 2; // 0.5

/* [Chamfer] */

// Chamfer at the bottom edge of the plate. Configurable for each edge individually (clockwise: north, east, south, west)
bottom_chamfer = [0, 0, 0, 0]; // 0.1
// Chamfer at the top edge of the plate. Configurable for each edge individually (clockwise: north, east, south, west)
top_chamfer = [0, 0, 0, 0]; // 0.1

/* [Plate wall] */

// Plate wall thickness. Can be specified for each direction individually (north, east, south, west). Note that this is *added* to the plate_size
plate_wall_thickness = [0, 0, 0, 0]; // 0.5
// Plate wall height. The first value is the height above the plate, the second value the height below the plate
plate_wall_height = [0, 0];
// Variable wall height, above the plate. Specified for each corner individually. Corners are SW, NW, NE, SE.
plate_wall_above = [0, 0, 0, 0];
// Variable wall height, below the plate. Specified for each corner individually. Corners are SW, NW, NE, SE.
plate_wall_below = [0, 0, 0, 0];

/* [openGrid] */
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

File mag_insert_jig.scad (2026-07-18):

include <gridflock.scad>
include <gridfinity-rebuilt-openscad/src/core/standard.scad>
use <gridfinity-rebuilt-openscad/src/core/base.scad>
include <gridfinity-rebuilt-openscad/src/core/gridfinity-rebuilt-holes.scad>

/* [Export Settings] */

// Part to export
part = "jig"; // [jig, pusher]

/* [Jig Settings] */

// Smoothness
$fn = 64;
// Visualize Cross Section
show_cross_section = false;
// Transparency Level
jig_alpha = 1.0;
// Height of the functional part of the bin to keep
jig_crop_height = 4.75;

/* [Disc Parameters] */

// Disc Radius
disc_radius = 16;
// Disc Height (Thickness)
disc_height = 4;
// Disc Chamfer size (mm) for the outer cylinder
disc_chamfer = 1.0;

/* [Cutout Refinement] */

// Rounding radius for the 2D cutouts (the corners)
cut_rounding = 1.0;
// Height of the tapered section at the TOP of the cut
cut_taper_height = 1.0;
// Scaling of the cut-out shape at the top exit (Set < 1.0 for "inward", > 1.0 for "funnel")
cut_taper_scale = 0.9;
// Scale of the straight functional section of the baseplate projection 
projection_scale = 1;

/* [Pusher Parameters] */

pusher_width = 30;
pusher_thickness = 4.85;
pusher_handle_height = 15;
pusher_stem_height = 1.85;
pusher_stem_width = 11;

/* [Magnet Parameters] */

magnet_clearance = 1.1;
magnet_outer_r = 3.8 * 1.05;
magnet_inner_r = 3.3 * 1.05;
magnet_hole_height = 20;
magnet_cutout_height = 2.25 * magnet_clearance;

/* [Advanced] */

// Overwrite GridFlock's settings
test_pattern = -1;
magnets = true;
connector_edge_puzzle = true;
connector_intersection_puzzle = false;
_edge_puzzle_direction_male = [false, false, false, false];
REFINED_HOLE_BOTTOM_LAYERS=3;

/* [Hidden] */

// Calculate hole position from the bottom edge
_hole_offset = (BASE_TOP_DIMENSIONS.x - 2 * _base_profile_max_mm.x) / 2 - HOLE_DISTANCE_FROM_BOTTOM_EDGE;

// Magnet hole options for Refined style
_hole_options_refined = bundle_hole_options(refined_hole=true);

/* [Modules] */

/**
 * @Summary 1x1 Bin Base Tool (JIG - Red)
 * @Details Represents the functional base of a bin that we want to test against or simulate
 */
module jig_bin_tool() {
  difference() {
    color([1.0, 0.2, 0.2, jig_alpha])
      intersection() {
        // Crop to the specified functional height
        translate([-50, -50, 0]) cube([100, 100, jig_crop_height]);

        difference() {
          union() {
            _base_bridge_solid(BASE_TOP_DIMENSIONS);
            base_solid(BASE_TOP_DIMENSIONS);
          }
          for (a = [0, 180]) {
            rotate([0, 0, a]) translate([_hole_offset, _hole_offset, 0]) block_base_hole(_hole_options_refined);
          }
          translate([0, 0, 4.4]) {
            rotate([0, 0, -45]) translate([0, 11]) linear_extrude(2) text("GridFlock", size=4.5, valign="bottom", halign="center");
          }
          _base_preview_fix();
        }
      }
  }
}

/**
 * @Summary 1x1 GridFlock Baseplate Rig (PLATE - Blue)
 * @Details The baseplate segment we are testing compatibility with
 */
module jig_baseplate_rig() {
  segment(trace=[[1], [1]], padding=[0, 0, 0, 0], connector=[true, true, true, true]);
}

/**
 * @Summary Solid Disc Body with Top Chamfer
 * @Details The blank disc before any functional cutouts are applied
 */
module jig_disc_blank() {
  color([0.5, 0.5, 0.5, jig_alpha])
    difference() {
      union() {
        cylinder(h=disc_height - disc_chamfer, r=disc_radius);
        translate([0, 0, disc_height - disc_chamfer])
          cylinder(h=disc_chamfer, r1=disc_radius, r2=disc_radius - disc_chamfer);
      }
      // Add magnet/screw holes to the disc itself
      for (a = [0, 180]) {
        mirror([0, 1, 0]) rotate([0, 0, a]) translate([_hole_offset, _hole_offset, 0])
              linear_extrude(height=100, center=true)
                projection()
                  block_base_hole(_hole_options_refined);
      }
    }
}

/**
 * @Summary Base shape for cutting from the disc
 * @Details Created by projecting the baseplate rig to 2D
 */
module jig_cutout_profile_2d() {
  offset(r=cut_rounding)
    scale([projection_scale, projection_scale, 1])
      projection()
        jig_baseplate_rig();
}

/**
 * @Summary Visual Assembly of Tool vs Rig
 */
module jig_assembly() {
  // 1. Visual Assembly of Tool vs Rig
  rotate([180, 0, 0]) {
    difference() {
      jig_bin_tool();
      jig_baseplate_rig();
    }
  }

  // 2. The Disc Tool
  // Disc atop the assembly with REVERSED compound cutouts to fit the baseplate
  translate([0, 0, 0])
    difference() {
      jig_disc_blank();

      translate([0, 0, -0.01]) union() {
          // A. Straight Section (Started at the bottom meeting face)
          linear_extrude(height=disc_height - cut_taper_height + 0.01)
            jig_cutout_profile_2d();

          // B. Tapered Section (at the TOP)
          translate([0, 0, disc_height - cut_taper_height])
            linear_extrude(height=cut_taper_height + 1, scale=cut_taper_scale)
              jig_cutout_profile_2d();
        }
    }
}

/**
 * @Summary Pusher output cutout shape
 */
module pusher_output_cutout() {
  linear_extrude(height=pusher_stem_height, center=true, scale=[1, 1])
    square([pusher_width, magnet_inner_r * 2], center=true);
}

minkowski_expand = 0.8;

/**
 * @Summary 2D Trapezoid for the main pusher pin, which pushes the magnet in
 */
module pusher_pin(positive) { 
  translate([0, magnet_top + 0.25]) {
    if (positive) polygon([[-pusher_thickness/2, 0], [-pusher_thickness/2*0.8, pusher_stem_height], [pusher_thickness/2*0.8, pusher_stem_height], [pusher_thickness/2, 0]]);
    else translate([0, pusher_stem_height/2]) square([pusher_thickness-minkowski_expand, pusher_stem_height-minkowski_expand], center=true);
  }
}

// width, height, length
aux_pin_dim = [5, 4, 13.5];
aux_pin_off = 4;
back_pin_dim = [5, 3, 14];

/**
 * @Summary 2D shape of auxiliary pins that absorb some bending force
 */
module aux_pins() {
  for (i = [0,1]) {
    mirror([i,0,0]) translate([-aux_pin_off, -_profile_height-0.25]) polygon([[0, 0], [0, aux_pin_dim.y], [-aux_pin_dim.x, 0]]);
  }
}

frame_strength = 5;
/**
 * @Summary Complete pusher assembly
 */
module pusher_combined(positive=true) {
  // main pin
  rotate([90, 0, 90]) {
    linear_extrude(pusher_stem_width - pusher_stem_height) pusher_pin(positive);
    skew = 1.9;
    translate([0, skew, pusher_stem_width - pusher_stem_height]) linear_extrude(pusher_stem_height, scale=[0.8, 0.7]) translate([0, -skew]) pusher_pin(positive);
  }
  // aux pins
  rotate([90, 0, 90]) linear_extrude(aux_pin_dim.z) aux_pins();
  // back pin
  translate([-frame_strength, -back_pin_dim.x/2, -_profile_height-0.25]) {
    rotate([0, 0, 90]) linear_extrude(back_pin_dim.y) {
      square([back_pin_dim.x, back_pin_dim.z - back_pin_dim.x/2]);
      translate([back_pin_dim.x/2, back_pin_dim.z - back_pin_dim.x/2]) circle(d=back_pin_dim.x);
    } 
  }
  // frame
  handle_chamfer = 0.75;
  handle_thickness = pusher_thickness + 2;
  rotate([90, 0, 90]) translate([0, 0, -frame_strength]) linear_extrude(frame_strength) {
    translate([-handle_thickness / 2, magnet_top]) square([handle_thickness, pusher_handle_height - handle_chamfer]);
    hull() {
      pusher_pin();
      aux_pins();
    }
  }
  // top of the handle gets a chamfer
  chamfer_square = [frame_strength, handle_thickness];
  translate([-frame_strength/2, 0, magnet_top + pusher_handle_height - handle_chamfer]) 
    linear_extrude(handle_chamfer, scale=[1-handle_chamfer*2/chamfer_square.x, 1-handle_chamfer*2/chamfer_square.y]) 
    square(chamfer_square, center=true);
}

/**
 * @Summary Pusher main cutout shape
                 */
module pusher_cutout() {
  minkowski() {
    union() pusher_combined(positive=false);
    // this minkowski creates a 1mm gap in all directions
    rotate([0, -90, 0]) linear_extrude(pusher_stem_width) square([minkowski_expand, minkowski_expand], center=true);
  }
}

/**
 * @Summary Magnet hole geometry
 */
module magnet_hole() {
  difference() {
    union() {
      cylinder(h=magnet_hole_height, r=magnet_outer_r, center=true);
      translate([magnet_outer_r / 2, 0, -2]) cube([magnet_outer_r, 14, 16], center=true);
    }
    cylinder(h=magnet_hole_height, r=magnet_inner_r, center=true);
  }
}

/**
 * @Summary Magnet hole cutout geometry
 */
module magnet_hole_cutout() {
  translate([0, -2, -5]) cube([1, 10, magnet_hole_height - 10], center=true);
  cylinder(h=magnet_hole_height, r=magnet_inner_r, center=true);
  translate([5, 0, -magnet_hole_height / 2 + magnet_cutout_height / 2])
    cube([10, magnet_inner_r * 2, magnet_cutout_height], center=true);
}

/**
 * @Summary Complete Jig with Pusher cutouts and Magnets
 */
module jig_with_pusher() {
  // Magnet position relative to center
  mag_pos_x = 8.2;
  mag_pos_z = (6 - 0.4) + (magnet_hole_height - 10) / 2;
  mag_pos_z_hole = 7.5 + (magnet_hole_height - 10) / 2;

  // Cutout positions
  out_pos_x = 22.5;
  out_handle_pos_z = 2 * pusher_stem_height;
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

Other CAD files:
opengrid/openconnect_slot_negative.3mf
test.scad
docs/animation-magnets.scad
docs/animation-size-smooth.scad
docs/animation-size.scad
docs/clickgroove-cross-section.scad
docs/irregular/irregular.scad
docs/title.scad

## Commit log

2026-01-21 Expand README with connector options and details
    Added detailed descriptions for Intersection and Edge puzzle connector options, including printing considerations and customization details.
2026-01-22 Add customizer categories
    [gridflock.scad]
2026-01-22 disable test pattern again
    [gridflock.scad]
2026-01-27 Add bottom chamfer (#4)
    * Add bottom chamfer
    * fix
    * also cut connectors
    * fix
    * extend chamfer to properly cut connectors
    [gridflock.scad]
2026-01-31 Fix zero plate corner radius
    [gridflock.scad]
2026-01-31 Switch to starnight theme
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2026-02-01 Explicit alignment option (#16)
    * Explicit alignment option
    * Flip the direction
    * docs
    * constraints
    [gridflock.scad]
2026-02-01 Cell override (#17)
    [gridflock.scad, irregular.scad]
2026-02-03 intersection connector fit adjustment
    [gridflock.scad]
2026-02-03 link to calibration files
2026-02-03 Top chamfer (#19)
    [gridflock.scad]
2026-02-03 Counterbore (#20)
    * Top chamfer
    * Counterbore for vertical screws
    [gridflock.scad]
2026-02-04 More intelligent staggered planning (#23)
    * More intelligent staggered planning
    Planning now does primitive multivariate optimization, instead of a simple two-pass heuristic. This avoids single-width segments in certain scenarios.
    Also fix missing end padding consideration in plan_axis_incremental_vars.
    Fixes #22
    * remove echo
    * remove echo
    [gridflock.scad, test.scad]
2026-02-05 Magnet Insert Jig (#21)
    * hello base
    * refined holes
    * two holes
    * feat: Implement GridFlock-based baseplate rig with configurable settings and transparency, and update the bin base tool.
    * refactor: Replace transparency toggle with cross-section visualization and numeric alpha, and update the bin base tool's hole pattern.
    * feat: Add disc dimensions, refactor the assembly module to subtract the baseplate rig from the bin tool, and include a disc component.
    * Refactor assembly logic to cut the disc with the baseplate projection, remove unused disc dimension variables, and adjust the main cutting cube dimensions.
    * feat: Introduce jig cropping height and parameterize disc dimensions an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
    [mag_insert_jig.scad]
2026-02-08 Chamfer mag insert jig handle
    [mag_insert_jig.scad]
2026-02-11 Add x axis segmentation algorithm selection (#25)
    Fixes #24
    [gridflock.scad]
2026-02-14 Move to editor toml (#26)
    * Move to editor toml
    * fix case
    * change url
2026-02-14 fix planning for very small bed sizes
    [gridflock.scad]
2026-02-14 Add bottom magnet glue option
    [gridflock.scad]
2026-02-16 Turn off magnets by default (#28)
    * Turn off magnets by default
    Analytics show most users don't use them, so let's turn them off.
    * fix toml
    [gridflock.scad]
2026-02-16 Add printer bed size presets (#29)
2026-02-18 Click latch (type 1) (#31)
    * Click latch (type 1)
    * off by default
    * Fix polyhedron face orientation
    * Documentation
    * Move parameter section
    [gridflock.scad, test.scad]
2026-02-21 Implement advanced filler settings (#33)
    * refactor to prepare for fractional cells
    * Implement advanced filler settings
    [gridflock.scad, mag_insert_jig.scad, test.scad]
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2026-02-22 ClickGroove (#34)
    * ClickGroove
    * Docs
    [clickgroove-base.scad, clickgroove-cross-section.scad, gridflock.scad]
2026-02-23 Move some parameters from the top tab
    [gridflock.scad]
2026-02-26 Fix click latch connection to grid
    [gridflock.scad]
2026-02-26 Fix jig
    [mag_insert_jig.scad]
2026-03-02 Change default rotation
    [gridflock.scad]
2026-03-04 Improve compatibility of bottom chamfer with ClickGroove
    [gridflock.scad]
2026-03-07 Fix edge connector + ClickGroove Fixes #35
    [gridflock.scad]
2026-03-07 Stacked printing (#37)
    * stacked prototype
    * Progress
    [gridflock.scad, test.scad]
2026-03-17 add link to modified magnet jig
2026-04-08 Improve magnets (#41)
    * magnet changes
    todo: doc images
    * generate docs
    * update date
    [gridflock.scad]
2026-07-18 Pin GitHub Actions to commit SHAs
    Add Renovate configuration to keep pinned action digests updated.
2026-07-18 Make jig documentation renders predictable
    [mag_insert_jig.scad]
2026-07-19 Pin local documentation renderer
2026-07-20 Variable wall height
    [gridflock.scad]
2026-07-20 Configure horizontal screws per edge
    [gridflock.scad]
2026-07-20 Collapse horizontal screw settings by default
2026-07-20 Remove horizontal screw tab description
2026-07-21 openGrid support
    [gridflock.scad, openconnect_slot_negative.3mf, openconnect_slot_negative_lock.3mf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]
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2026-09-08 Lightweight grids (#65)
    * Add lightweight (skeletonized) plates
    * Rename lightweight setting to hollow
    The lightweight category may gain other weight-saving techniques in
    the future, so the specific skeletonization toggle and its wall
    thickness parameter are renamed from lightweight/lightweight_wall to
    hollow/hollow_wall. The Lightweight category name (README section,
    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
    [gridflock.scad]
2026-10-01 Add bottom magnets for mounting the plate on metal surfaces (#68)
    Glue-in magnet pockets on the underside of the plate at cell
    intersections. Placement reuses the vertical screw intersection
    classification (plate corners, segment corners, other); edge
    intersections are excluded since they lie on the plate edge or a
    connector. The pocket size is checked against the material available
    at the intersection.
    [gridflock.scad]
2026-10-01 Add bottom_magnet_floor for glue-less bottom magnets
    A floor below the pocket keeps the magnets in the plate. The magnets can
    be embedded with a print pause, or, if the pocket height exceeds the
    plate height, inserted from the top through a hole.
    [gridflock.scad]
2026-10-01 Move bottom magnets section after horizontal screws
    Keeps the bin magnets and click latch next to each other, and puts the
    niche bottom magnets option with the other plate mounting options.
    [gridflock.scad]
2026-10-01 Never place bottom magnets on segment edges
    Plate corners are classified before segment edges, so a plate corner on
    a segment edge (e.g. with one-column segments) got a pocket that cut
    through the intersection puzzle connector.
    [gridflock.scad]
2026-10-01 Show bottom magnet holes closer and at an angle in README images
2026-10-01 Merge bottom magnets into vertical screws, add magnet release hole
    Instead of a separate section with duplicated location settings, the
    vertical screw section (now labelled "Intersection Holes") gets a
    vertical_screw_style option to switch between screw holes and magnet
    pockets. Parameter names stay the same, so existing configs keep
    working. Edge locations are ignored for magnets.
    Also adds vertical_screw_magnet_release_diameter, a small hole through
    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
    [gridflock.scad]
2026-10-01 Simplify intersection magnets to reuse screw placement unchanged
    Drop the classification refactor and the special segment edge
    exclusion. Magnets now follow exactly the same location rules as
    screws, including edges if the user enables them.
    [gridflock.scad]
2026-10-01 Remove intersection magnet error checking
    Drop the pocket fit assert, the hollow mode assert and editor warning,
    and the open-top special case (a pocket taller than the plate simply
    cuts through the top).
    [gridflock.scad]
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2026-10-08 Keep solid material around the puzzle connectors in hollow mode with hollow_connector_fill (#70)
    [gridflock.scad]
